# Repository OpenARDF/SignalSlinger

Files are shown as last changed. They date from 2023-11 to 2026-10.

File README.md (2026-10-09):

# SignalSlinger

SignalSlinger is an open-source 80-meter radio orienteering (ARDF) transmitter kit for the 3.5 MHz to 3.7 MHz amateur band. It supports classic, sprint, and foxoring events, with a high-accuracy real-time clock for synchronized transmissions and scheduled start and finish times.

## Product Photo

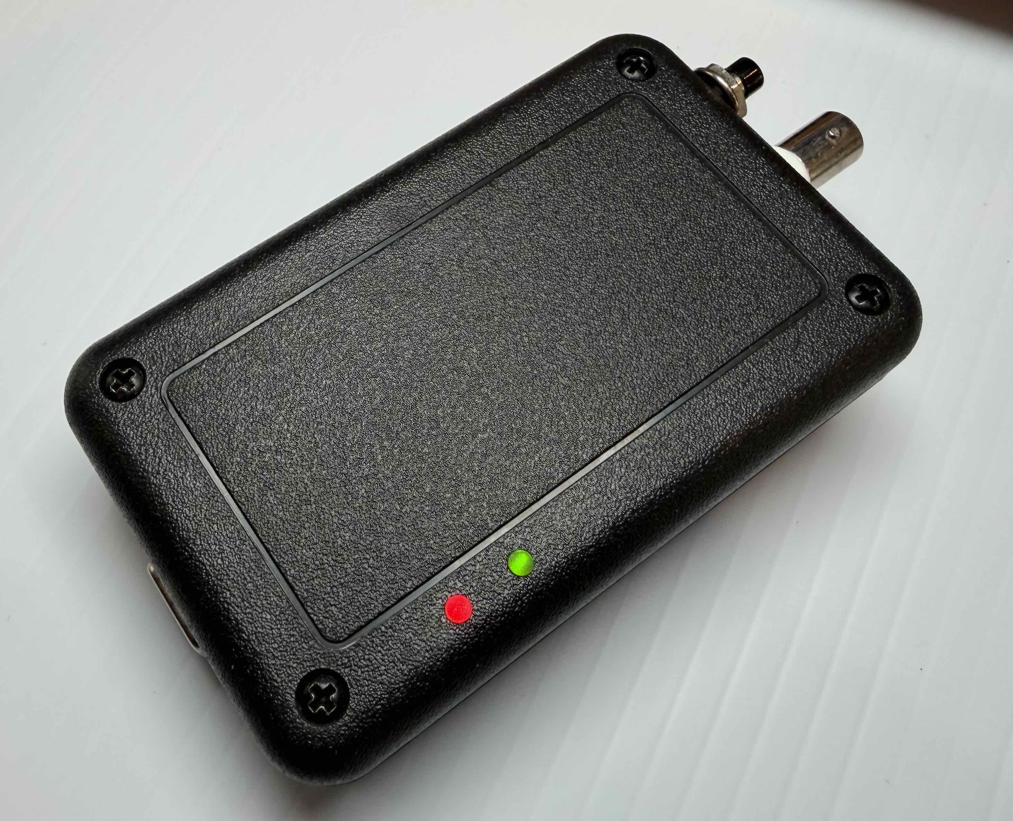
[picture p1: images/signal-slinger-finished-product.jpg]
SignalSlinger finished product


## Documentation

* [User Manual](https://docs.google.com/document/d/1eX7xH3cDyRNS-MVg13EojpP8IB8bDgrdszM48J0sn7k/edit?usp=sharing)
* [Bill of Material](https://docs.google.com/spreadsheets/d/182rCsEmR_KNoESYd0NLeVXOi867AKD0zTovbhvcYbqc/edit?usp=sharing)
* [GitHub Releases](https://github.com/OpenARDF/SignalSlinger/releases)

## Availability

SignalSlinger is available in kit form from Backwoods Orienteering Klub. [Order the SignalSlinger Transmitter Kit](https://backwoodsok.org/store/SignalSlinger-Transmitter-Kit-p799230332) or visit the product page for current pricing, availability, shipping information, and kit details.

## Updating Software

This `main` branch corresponds to the current stable firmware release. Download the update file that matches your hardware revision:

* `SignalSlinger-Update-v2.0.7-HW-3.5.hex`
* `SignalSlinger-Update-v2.0.7-HW-3.4.hex`

Use SerialSlinger for normal updates on devices that already support software updates. For first-time bootloader setup, use the matching complete release bundle and an approved programmer over the board's UPDI programming header (`P101`). Always choose the file that matches your hardware revision, and do not modify fuses or disable UPDI outside the documented setup flow.

For complete programming steps, setup-bundle usage, and hardware connection details, see the [User Manual](https://docs.google.com/document/d/1eX7xH3cDyRNS-MVg13EojpP8IB8bDgrdszM48J0sn7k/edit?usp=sharing). If you want the current development branch instead of the stable public release, switch to the `Development2` branch and use the release files referenced there.

## Firmware Development

Firmware source and build scripts live in [`Software/AVR128DA28`](Software/AVR128DA28).

For the current development workflow, start here:

* [`Software/AVR128DA28/CODEX_WORKFLOW.md`](Software/AVR128DA28/CODEX_WORKFLOW.md) for branch and patch-verification expectations
* [`Software/AVR128DA28/RELEASE_WORKFLOW.md`](Software/AVR128DA28/RELEASE_WORKFLOW.md) for release preparation and dual-target asset checks
* [`Software/AVR128DA28/build-firmware.ps1`](Software/AVR128DA28/build-firmware.ps1) for the standard local firmware build
* [`Software/AVR128DA28/verify-firmware-hashes.ps1`](Software/AVR128DA28/verify-firmware-hashes.ps1) for dual-target `.hex` build and SHA256 verification

## Related Projects

* [SignalStreamer](https://github.com/OpenARDF/SignalStreamer), a matching antenna
* [SignalSnagger](https://github.com/OpenARDF/SignalSnagger), a companion receiver project
* [SerialSlinger](https://github.com/OpenARDF/SerialSlinger), a serial terminal and logging companion for SignalSlinger configuration and monitoring

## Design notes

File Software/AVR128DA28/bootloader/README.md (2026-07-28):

# SignalSlinger Bootloader

This directory contains the first-stage SignalSlinger AVR128DA28 bootloader work.

Current scope:

- reserve an 8 KiB boot section
- keep the application start fixed at byte address `0x2000`
- use `USART1` on the existing SignalSlinger serial pins, `PC0` TX and `PC1` RX
- latch SignalSlinger power on with `POWER_ENABLE`/`PA3` before waiting for serial input
- turn both front-panel LEDs on during the bootloader startup window for immediate power-on feedback, blink them at the wake-authorization cadence when the power button is held, then pass the held-button state to the app at handoff
- stay in the bootloader when no valid app reset vector is present, when the serial updater sends `U` during the startup window, or when the front-panel switch is held during a non-power reset
- otherwise jump to the relocated application

The bootloader now accepts a deliberately small page programming protocol. It only erases or writes full, page-aligned APPCODE pages and rejects any frame whose address would touch the boot section.

The running application still accepts the `UPD` command at the normal SignalSlinger serial rate. Before issuing the software reset, the app writes a short update-request marker into `GPR1`; the bootloader consumes that marker on the next software reset and stays in update mode without relying on a narrow serial timing window. After the app resets, the bootloader runs the programming protocol at `115200` baud. On the current SignalSlinger firmware image this writes the app in about 40-45 seconds, or about a minute with default serial page-CRC verification, which is a useful improvement without pushing the serial link hard.

On SignalSlinger hardware, the front-panel switch is also the momentary power-on source. A normal cold power-on therefore starts with that switch held. The bootloader treats POR/BOR resets specially: it latches `PA3` high immediately so the board stays powered, turns both LEDs on for immediate feedback, blinks both LEDs at the wake-authorization cadence while the button remains held, ignores switch-held bootloader entry for that cold-start case, and then jumps to the app unless serial `U` arrives, the app reset vector is missing, or the app has requested update mode through `GPR1` before software reset. At app handoff, it records whether the power button is still held in `GPR0`; the app consumes that marker after its GPIO initialization so it can preserve startup LED feedback only for real held-button power-on. This lets the application take over the normal power latch/off behavior and LED policy without showing a long solid-LED hold when external power appears without a button press.

## Address Map

The AVR128DA28 has 131072 bytes of program flash and 512-byte flash pages. `BOOTSIZE` and `CODESIZE` fuses are expressed in 512-byte pages.

Initial bootloader allocation:

- `BOOTSIZE = 16` pages
- boot section: `0x00000` through `0x01FFF`
- relocated application start: `0x02000`
- `CODESIZE = 0`, leaving the remainder as application code space

## Build

From `Software/AVR128DA28` on the Windows/Microchip Studio environment:

```powershell
powershell -ExecutionPolicy Bypass -File .\build-bootloader.ps1 -Configuration Release
```

Build the matching relocated application with:

```powershell
powershell -ExecutionPolicy Bypass -File .\build-relocated-firmware.ps1 -Configuration Release
```

That helper uses a temporary makefile and injects `-Wl,--section-start=.text=0x2000`; it does not alter the normal `SignalSlinger/Release/Makefile`. It removes the previous final firmware outputs before linking and then verifies the generated map so stale non-relocated output cannot be mistaken for a bootloader-ready app image.

## Provisioning Script

Use the guarded provisioner to build, merge, program, verify, and validate a bootloader-enabled unit:

```powershell
powershell -ExecutionPolicy Bypass -File .\provision-bootloader.ps1 -Port COM6
```

Check programming PC prerequisites without touching target hardware:

```powershell
powershell -ExecutionPolicy Bypass -File .\provision-bootloader.ps1 -CheckPrereqs -SkipBuild -SkipSerialValidation
```

The script creates `tmp\SignalSlinger-bootloader-combined.hex` from the bootloader HEX and relocated app HEX, chip-erases the target, programs and verifies the combined flash image, reads fuses, verifies `CODESIZE = 0x00` and `BOOTSIZE = 0x10`, then runs the bootloader serial protocol test.

Fuse writes are deliberately opt-in:

```powershell
powershell -ExecutionPolicy Bypass -File .\provision-bootloader.ps1 -Port COM6 -ProgramFuses -ConfirmFuseWrite
```

Without those two switches, the script reads and checks fuses but does not change them.

On Windows, the provisioner uses Microchip Studio `atprogram` by default. On macOS or Windows, it can use `pymcuprog`:

```powershell
pwsh ./provision-bootloader.ps1 -Backend Pymcuprog -SkipBuild -BootloaderHexPath ./bootloader/Release/SignalSlingerBootloader.hex -ApplicationHexPath ./SignalSlinger/Release/SignalSlinger.hex
```

The PowerShell build helpers remain Windows/Microchip Studio centered. The
repository also has a pinned native macOS build path:

```sh
just avr-setup-macos
just avr-doctor
just avr-boot-chain-build
```

That build writes the bootloader and both hardware revisions of the relocated
application beneath ignored `tmp/avr-*` directories, verifies the `0x2000`
application start and 8 KiB bootloader boundary, and records hashes, sizes, and
warnings in `build-evidence.json`. See
[`BUILD_ENVIRONMENT.md`](../BUILD_ENVIRONMENT.md) for the exact compiler/device
pack and individual build recipes.

Required programming PC software:

- Windows build/provision path: PowerShell, Microchip Studio 7 with the AVR-Dx device pack and AVR GCC toolchain, Atmel-ICE drivers, and a USB serial driver for the SignalSlinger serial adapter.
- Windows or macOS provision-only path: PowerShell 7, Python, `pymcuprog`, Atmel-ICE USB access, and prebuilt bootloader/application HEX files. `pymcuprog` is installed with `python -m pip install pymcuprog`; use a Python version with available `hidapi` wheels for the host architecture.
- Bench validation path: Atmel-ICE on UPDI plus a USB serial adapter connected to SignalSlinger USART1.

## Release Package

Firmware with software-update support starts at version `2.0.0`. Firmware versions below `2.0.0` are legacy builds and should not be packaged as bootloader-capable release assets.

Build the files that should be attached to a GitHub release:

```powershell
powershell -ExecutionPolicy Bypass -File .\build-release-package.ps1
powershell -ExecutionPolicy Bypass -File .\validate-release-package.ps1
```

To build packages for both supported hardware versions:

```powershell
powershell -ExecutionPolicy Bypass -File .\build-all-release-packages.ps1
```

The packages are written under `release-packages\...` by default and use names meant to be understandable outside the firmware bench. Files that depend on the SignalSlinger hardware version include `HW-3.4` or `HW-3.5` in their name:

- `SignalSlinger-Update-...hex`: the file SerialSlinger should use for normal software updates
- `SignalSlinger-First-Install-...hex`: the file workshop setup tools should use for a new board with a programmer
- `SignalSlinger-Setup-Helper-...hex`: the helper file used by workshop setup tools
- `SignalSlinger-Release-Info-...json`: the information SerialSlinger reads automatically
- `SignalSlinger-Checksums-...txt`: optional file-integrity checks
- `README-SignalSlinger-...txt`: short plain-language notes for the release folder

The release-info JSON keeps the unavoidable details for software: board version, update speed, page size, app start address, bootloader version, protocol version, and SHA-256 hashes. Normal users should not need those details; SerialSlinger can read them and choose the right update file in the background.

Run `validate-release-package.ps1` before uploading assets. It checks that the files named by the release info are present, hashes match, the normal update starts at the app address, the first-install image includes both bootloader and app, and the bootloader helper does not overlap app space.

For GitHub releases, upload the unzipped `SignalSlinger-Update-...hex` for each supported hardware version for the common SerialSlinger update path, plus the matching versioned `SignalSlinger-...-Release-Files.zip` containing the complete set of files for that hardware version.

## Hardware Version Selection

SerialSlinger should use the firmware already running on the device as the first guide for choosing the update file. Firmware `2.0.0` and newer supports the `INF` app command at 9600 baud. It replies with compact machine-readable lines such as:

```text
* INF product=SignalSlinger update=UPD
* INF sw=2.0.0 hw=3.5 app=0x2000 baud=115200
* INF uid=314A323536384E171D00321700000000
```

The `uid` field is the AVR's factory-programmed 16-byte serial number rendered as 32 uppercase hexadecimal characters. It remains stable across firmware updates and settings changes, allowing SerialSlinger to detect when a different transmitter replaces the previously loaded unit behind the same USB serial adapter. Firmware that predates this field remains compatible and simply omits the line.

The `hw` field should match the release package `board` field and the `HW-3.4` or `HW-3.5` text in the file name before SerialSlinger enters update mode. If `INF` is not supported, SerialSlinger can fall back to parsing the older human `VER` response, for example `SW Ver: 1.2.2 HW Build: 3.5`. Firmware versions below `2.0.0` should be treated as legacy: use `RST` plus the bootloader-catch path instead of relying on `UPD`.

The `hw` field reports the hardware target used to build the currently installed application. It is the best default for normal updates, but it is not an independent hardware probe. If a board is known or suspected to have the wrong hardware build installed, SerialSlinger should offer a deliberate recovery/override path that lets the user choose the physical hardware version, then confirms the new app reports the chosen `hw` after the update.

The bootloader `?` response identifies the bootloader protocol and flash geometry, but the bootloader binary is hardware-neutral. Hardware-version selection therefore belongs to the running app response and release metadata, before the app hands control to the bootloader.

## Serial Update Frames

All multi-byte fields are little-endian. CRC is CRC-16/CCITT-FALSE initialized to `0xFFFF` and covers the command byte plus the frame body, but not the transmitted CRC bytes.

- `?`: print bootloader information
- `U`: enter or confirm bootloader update mode
- `R`: jump to the app when the app reset vector is programmed
- `E <addr:u32> <crc:u16>`: erase one 512-byte page
- `W <addr:u32> <payload:512 bytes> <crc:u16>`: write one erased 512-byte page
- `C <addr:u32> <crc:u16>`: report CRC-16/CCITT-FALSE of one 512-byte page as `OK crc 0xAAAAAAAA CCCC`

`addr` must be page-aligned and the complete page must be inside `0x02000` through `0x1FFFF`. The bootloader responds with `OK erase`, `OK write`, `OK crc ...`, or `ERR ...`. USART framing, parity, or overflow faults are reported as `ERR serial XX`.

The `?` response is intentionally machine-readable for host programmers. New fields are added append-only so host tools can keep parsing the tokens they understand:

```text
SignalSlinger BL0.13 proto=1 minproto=1 maxproto=1 app=0x2000 page=512 flash=131072 baud=115200 boot=16 write=0x2000-0x1FFFF features=appmark,pagecrc,resetlast cmds=U,R,?,E,W,C
```

The `write` field names the only flash range the bootloader will erase or program. The `features` field advertises the app reset marker (`appmark`), per-page CRC command (`pagecrc`), and reset-vector page written last for interrupted-update recovery (`resetlast`).

During a firmware update, the bootloader toggles red as erase/write flash operations are accepted and completed, and toggles green as write payload bytes are received. Rejected frames and NVM/serial errors leave red on and green off until later update activity changes the indication.

## Serial Firmware Update

Build the relocated application, then update a unit that is already running the bootloader:

```powershell
powershell -ExecutionPolicy Bypass -File .\build-relocated-firmware.ps1 -Configuration Release
powershell -ExecutionPolicy Bypass -File .\update-firmware-serial.ps1 -Port COM6 -SkipBuild -NoReset
```

For a normal field update from the running application, let the script send `UPD` to the app and catch the bootloader entry window:

```powershell
powershell -ExecutionPolicy Bypass -File .\update-firmware-serial.ps1 -Port COM6 -RequestBootloaderFromApp
```

The updater defaults to `-AppBaud 9600` for the `UPD` command and `-BootBaud 115200` for the bootloader frames. The legacy `-Baud` parameter is still accepted as an alias for `-BootBaud`.

For bench validation with Atmel-ICE attached, add `-VerifyWithUpdi` to verify the programmed app flash after the serial update:

```powershell
powershell -ExecutionPolicy Bypass -File .\update-firmware-serial.ps1 -Port COM6 -RequestBootloaderFromApp -VerifyWithUpdi
```

The updater parses the relocated Intel HEX file, rejects records outside APPCODE, erases the reset-vector page first, writes all other pages, then writes the reset-vector page last. By default it asks the bootloader for a CRC of each programmed page and compares it with the image data, giving serial-only verification without Atmel-ICE. Use `-SkipSerialVerify` only for bench timing or protocol debugging.

After sending the bootloader `R` command, the updater reopens the serial port at the app baud rate, drains startup text, sends `INF`, and confirms the updated app is running with the expected product, version, hardware version, app start address, and update baud. Use `-SkipAppConfirm` only when deliberately testing a recovery case where the app is not expected to start.

If an update is interrupted after the reset-vector page is erased, the application will not start. That is intentional: on the next reset, the missing app vector keeps the bootloader resident so the unit can be restored with:

```powershell
powershell -ExecutionPolicy Bypass -File .\update-firmware-serial.ps1 -Port COM6 -SkipBuild -NoReset -VerifyWithUpdi
```

## Bench Protocol Tests

With Atmel-ICE and the USB serial adapter attached, run the bootloader protocol hardening test from the app `UPD` path:

```powershell
powershell -ExecutionPolicy Bypass -File .\test-bootloader-serial.ps1 -Port COM6 -RequestBootloaderFromApp
```

Run the same test through UPDI reset plus serial `U` entry:

```powershell
powershell -ExecutionPolicy Bypass -File .\test-bootloader-serial.ps1 -Port COM6
```

The test uses page `0x1FE00` as scratch, validates good erase/write/CRC behavior, rejects bad CRCs, rejects unaligned, boot-section, and past-flash addresses, verifies truncated-frame timeout handling, confirms the bootloader remains responsive afterward, and erases the scratch page before returning to the app.

For repeatability testing, run multiple full updates from the app `UPD` path:

```powershell
powershell -ExecutionPolicy Bypass -File .\test-bootloader-repeatability.ps1 -Port COM6 -Count 3
```

By default each repeatability run verifies every page over serial CRC, verifies the programmed application over UPDI, and reports programming and wall-clock time. The script writes timestamped run artifacts under `tmp\bootloader-repeatability\...`: one log per update plus `summary.csv` and `summary.json` with the git commit, HEX path, HEX SHA-256, baud rates, verification settings, and per-run timings.

Use `-OutputDir <path>` to choose a durable evidence folder. Use `-SkipSerialVerify` only when measuring raw programming time; use `-NoVerify` only when Atmel-ICE is not attached.

## Provisioning Notes

Do not program bootloader fuses casually. The safe provisioning flow should remain:

1. build the bootloader
2. program the bootloader over UPDI
3. verify fuse backups exist
4. set `BOOTSIZE = 16` and `CODESIZE = 0`
5. verify `BOOTSIZE = 0x10` and `CODESIZE = 0x00`
6. build and program a relocated application
7. run `test-bootloader-serial.ps1` through both app `UPD` and UPDI reset entry
8. run one full serial update with `-VerifyWithUpdi`
9. confirm the application responds at the normal app baud

The normal production firmware makefile should remain unmodified while the relocated build path is still being proven.

## Recovery Checklist

If a unit does not start the app after an attempted update:

1. connect the USB serial adapter at `115200` baud
2. send `?` and confirm the `SignalSlinger BL...` banner
3. if there is no response, reset with UPDI while sending `U`
4. run the serial updater with `-NoReset -VerifyWithUpdi`
5. confirm the app responds at `9600` baud

If serial recovery does not respond, use UPDI to reprogram the bootloader and relocated app, then re-check `BOOTSIZE` and `CODESIZE`. Do not change fuses unless UPDI communication is known-good.

Reference validation sequence before broader use:

1. `powershell -ExecutionPolicy Bypass -File .\build-bootloader.ps1 -Configuration Release`
2. `powershell -ExecutionPolicy Bypass -File .\build-relocated-firmware.ps1 -Configuration Release`
3. `powershell -ExecutionPolicy Bypass -File .\test-bootloader-serial.ps1 -Port COM6 -RequestBootloaderFromApp`
4. `powershell -ExecutionPolicy Bypass -File .\test-bootloader-serial.ps1 -Port COM6`
5. `powershell -ExecutionPolicy Bypass -File .\test-bootloader-repeatability.ps1 -Port COM6 -Count 3`

UPDI must remain available as the recovery path throughout bootloader development.

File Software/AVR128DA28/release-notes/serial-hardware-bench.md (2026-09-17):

# Serial hardware regression bench

This bench runs production firmware on an identified attached **HW 3.5 Classic
Fox 3**, using its RTC, interrupt handlers, scheduler, serial transport, and GPIO
readback. It changes the RTC and schedule temporarily. It leaves transmissions
stopped, restores the original saved schedule and the computer's local wall clock,
and disables tracing on normal completion, assertion failure, or SIGTERM.

## Commands

Existing commands remain compatible: `UI S` reports UI/clone state, `UI P n`
queues a counted-button action directly to the foreground dispatcher, and `UI C`
clears clone UI latches. New commands extend that interface:

| Command | Function |
| --- | --- |
| `UI D` | Bench capability version, coherent state snapshot, LED/GPIO and synthesizer state, pending input, temperature freshness, runtime and last button-action/wake diagnostics. |
| `UI B 1-750` | Hold a simulated button closed for this many ordinary button-sampling periods, then release. A period is nominally 20 ms; 10 is a short press, 100 exercises hold preview, and 250 exceeds the normal long-hold threshold. |
| `UI T 1-30` | Clear and enable a 32-record RAM ring at the requested interval in RTC seconds. |
| `UI T 0` | Stop recording, preserving retained samples. |
| `UI T` | Freeze and print the ring in chronological order, ending with `UI T end`. |

`UI B` enters the normal button detector after physical debouncing. It exercises
press counting, hold preview, hold intent, long-hold thresholds, and foreground
handling. It does **not** simulate electrical bounce, the physical wake interrupt,
or hold-to-wake authorization. It refuses overlapping injection, a physically
closed button, sleeping/not-yet-authorized operation, pending sleep, master/clone
mode, and already pending button commands. It releases automatically and preserves
the pending release across standby so subsequent holds re-arm normally.

Synthetic input and timer tracing are off after reset; UART error counters start at zero. The hooks do not force transmitter
outputs, spoof temperature or RTC ticks, override thermal protection, or write
EEPROM. Normal user commands used to configure tests do write settings and session
history. Trace capture piggybacks on the existing one-second RTC interrupt, with
no serial output, ADC work, or extra scheduled wake-ups. A dump freezes recording;
it does not provide an endless live stream. At interval 10 it retains about five
minutes of samples; older samples are overwritten. Snapshots are scheduler/GPIO
observations, not calibrated RF, optical, or power measurements.

`UI D` also reports saturating UART overrun, framing, and parity error counts
since reset. Damaged lines are discarded through their terminator and produce an explicit
serial-receive error; a truncated setting must never execute. Clean lines retain
the existing parser behavior. The standard `just hardware-bench` recipe sends unpaced command bytes. The
underlying script retains its conservative 10 ms default for investigations;
`--byte-gap-ms 0` explicitly requests the unpaced regression run. Pacing was the initial diagnostic workaround for EEPROM-induced CPU stalls.
The EEPROM fix waits for readiness before reads and between multi-byte writes,
allowing already-enabled interrupts to continue. Use unpaced traffic and the
EEPROM regression gate below to verify the fix; paced success alone is insufficient. Errors are retained in evidence, never silently retried. The runner uses a kernel-exclusive serial handle on macOS
and stops on incomplete or error replies.

Snapshot/trace `at` uses device wall-clock epoch fields, **not UTC**. `onair` is the
signed slot countdown; `sleep` uses the existing runtime enum; `day` is zero-based;
`key` and `demo` are remaining 300-Hz timer ticks. `flags` is a bit mask:

| Bit value | Meaning |
| --- | --- |
| 1 | MCU is in the foreground standby loop |
| 2 | Event enabled |
| 4 | Event commenced |
| 8 | Manually launched event |
| 16 | Run until canceled |
| 32 | Last confirmed synthesizer key state |
| 64 | Synthesizer initialized |
| 128 / 256 | Red / green LED pin readback high |
| 512 | Thermal shutdown latched |
| 1024 | Current-day cancellation latched |
| 2048 | Wake authorization complete |

## Running

Use the existing serial update script after `just check` and the target firmware
build. Do not open a second serial owner. The runner checks the full requested UID,
hardware, bench capability, and Classic Fox 3 profile before changing settings.
It uses pyserial and records timestamped raw traffic plus structured case results.
Wake synchronization requires a complete INF command response; a startup banner
containing the device UID is insufficient. If startup enters sleep after the
first wake pulse, the runner sends another wake pulse before probing. Read-only
probe retries are bounded and logged; setting-changing commands are never replayed.

```
just hardware-bench /dev/cu.usbserial-DEVICE EXPECTED_FULL_UID /absolute/evidence/path
```

The recipe includes the longer quiet RTC sleep/wake and duration tests. Use the
script's `--case` option to reproduce one named scenario, or `--start-at` and
`--stop-before` to select a range. `--restore-from` accepts
a previously saved `CLK` report, useful when a firmware update reset the clock.
The original scheduled run must be stopped before dedicating a device to this
bench; this runner restores configuration and a stopped state, not prior live
execution or the prior history ring. Test timestamps use a fixed synthetic calendar
through the ordinary clock-setting protocol, while elapsed delays use real time.

On failure, read `results.json` and `serial.jsonl`; the restore result is explicit.
An abrupt host crash, power cut, or SIGKILL cannot execute software cleanup. For
fully unattended fault/soak work, add an independent hardware power/RF cutoff.
The framework does not erase history or alter calibration, callsign, frequency,
battery thresholds, thermal settings, or firmware version.

## Limits

Physical button wake and bounce, visible LED output, RF frequency/power/spectrum,
standby current, supply brownouts, and actual thermal trips require the corresponding
connected external instruments or fixture. Firmware pin/synthesizer readback is
valuable evidence but cannot establish those measurements. An unavailable instrument
is a coverage gap, never a passed test. A second device and HW 3.4 are required for
physical clone/mixed-board coverage. Both firmware targets still receive build checks.

## Optional serial latency diagnostic build

`just avr-latency-build-hw 3.5` builds a separate image in
`tmp/avr-release-relocated-hw-3-5-latency`. This enables
`SIGNALSLINGER_LATENCY_DIAGNOSTICS`; normal builds compile every timing scope out.
When first added, these hooks left the normal HW 3.5 image byte-for-byte
identical to its predecessor; subsequent functional fixes intentionally change
that image. The diagnostic image adds execution
overhead and must be identified separately in test evidence.

After installing that image with the existing serial updater:

| Command | Diagnostic behavior |
| --- | --- |
| `UI L 1` | Clear bounded timing/fault records and enable capture. |
| `UI L 0` | Disable capture, preserving records. |
| `UI L` | Freeze and report metrics plus the first 16 overflow observations. |

No timer configuration, interrupt priority, ADC, EEPROM, or scheduled wake-up is
added by the instrumentation itself. It reads the existing 32768-Hz RTC counter;
one tick is approximately 30.5 microseconds. Scope times wrap after one RTC
period (about one second), so this is a short-latency diagnostic, not a general
long-operation profiler. Captures must not span explicit clock resets. A scope's
elapsed time includes interrupts that preempt it; a long foreground operation is
not automatically evidence of interrupt starvation.

Metric IDs: 0 RTC handler, 1 TCB0 handler, 2 LED handler, 3 high-priority TCB2
handler, 4 key control, 5 I2C write, 6 I2C read, 7 EEPROM byte write, 8 EEPROM word
write, 9 EEPROM dword write, 10 EEPROM float write, 11 RX parser, 12 EEPROM read,
13 history append. `max` and `irq_max` are RTC ticks; `busy` counts entries while
EEPROM was busy; `over2ms` counts scopes lasting at least 66 ticks. TCB2's `gap`
is the longest entry-to-entry interval, normally approximately 2 ms in this build.
The scope-mask bit at position N denotes an active scope with ID N.

Fault observations require both an unread byte (`RXCIF`) and its overflow flag;
old RXDATAH error bits without RXCIF are stale, not additional overruns. Fault
records and the saturating UART error counters are observations, not a count of
individual lost bytes. `UI L 1` does not reset the UART counters.

`just serial-latency-bench PORT FULL_UID NEW_OUTPUT_DIRECTORY` runs the broader
capture sequence. The script also supports `--focus-demo --repeats 3` to repeat
the carrier-to-demo transition and capture a timed-setting write. It reuses the
hardware bench's identity checks, exclusive port, evidence log, and restoration.
The receive load consists of continuous comment text, avoiding a flood of queued
commands and replies. Selected captures prefix that text with an explicit button
or timer-setting command. A successful capture means the investigation completed;
read `latency.json` and the raw traffic to determine whether overruns occurred.
Restore the normal image and the current clock after the diagnostic session.

## EEPROM serial regression gate

`just serial-eeprom-regression PORT FULL_UID NEW_OUTPUT_DIRECTORY` repeats the
previously failing carrier-to-demo transition three times and changes a stored
finish time, under continuous 9600-baud receive traffic. It requires a diagnostic
image, zero UART overrun/framing/parity counters, no captured overflow events, and
a maximum high-priority timer service interval below 4 ms (normally about 2 ms).
It also verifies carrier/demo entry and the saved finish time, so a dropped
command cannot produce a false pass.

The underlying script accepts `--normal-image --require-clean` to exercise the
same traffic and state/error checks on ordinary firmware, omitting optional
timing commands. `--require-clean` can also be used for its broader sequence,
which covers scheduled-start and carrier-expiry transitions. Capturing evidence
without this option remains an investigation, not a zero-error regression pass.

The low-level `test-eeprom-access.py` test runs the production accessor bodies
against a busy-memory model, checking read/write readiness, ascending byte order,
floating-point bit preservation, enabled/disabled interrupt state, and partial
writes. Removing either readiness guard must fail the test. The separate journal
test covers power cuts, ring wraparound and checksum rejection; host simulation
does not substitute for physical supply-interruption testing.

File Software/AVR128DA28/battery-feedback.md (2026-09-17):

# External battery feedback

The green LED uses the most recent confirmed external-battery voltage. A healthy
battery can therefore produce steady green even while its power-control cable is
deliberately switched off. During normal status display, green blinks fast when
an internal battery is detected, its voltage is at or below the configured low
threshold (default 3.8 V), and external voltage is strictly below 6.0 V. Charging
state does not affect this indication. Other readings at or below 6.0 V produce
slow green blinking, including exactly 6.0 V; readings above 6.0 V produce steady
green. This is a voltage indication, not a capacity estimate.

Awake firmware uses the existing periodic ADC scheduler:

- A transmission or charging power-on requests a fresh external measurement after
  at least 10 ms of settling, even when the LEDs are dark.
- With visible LEDs and power already requested, external voltage is measured
  approximately once per second.
- With visible LEDs and managed external power disconnected, a temporary
  measurement client enables the battery, waits at least 10 ms, samples, and
  releases its request. This repeats approximately every ten seconds. It never
  enables the RF chain. Charging or transmission can retain power independently.
- LED timeout cancels temporary probes and disables the faster polling. Normal
  awake monitoring of an enabled supply keeps its approximately eight-second
  interval. The legacy timer constants are not changed for other services.
- With external battery control disabled, measurements never pulse the auxiliary
  output, which may be used for the HW 3.4 fan.

The periodic service completes a conversion on a subsequent 300 Hz timer tick,
so a normal probe lasts about 13 ms, with extra delay if another conversion is
in progress. A lost ADC
conversion releases the temporary request; a separate 100 ms request deadline
bounds a probe even when the ADC scheduler cannot start its conversion.

`BAT` reports the last confirmed external measurement rather than sampling the
intentionally disconnected jack. Its internal measurement and foreground
temperature reads temporarily own the ADC; any displaced periodic conversion is
retried, so results are not attributed to the wrong channel.

The ADC allows 16 ADC clocks for initialization after enabling its reference.
Temperature-channel acquisitions use 11 sample-length clocks at the 375 kHz ADC
clock (29.3 microseconds), meeting the AVR128DA sensor's 25-microsecond startup
and 28-microsecond sampling requirements. Voltage channels restore the short
sampling window. The input is selected before enabling the ADC/reference so
the initialization delay cannot retain the previous input for the first sample.
This prevents immediate `TMP` queries after ADC restart from
reporting false heat and changing the fan state. Sampling cadence and sleep
shutdown remain unchanged. `scripts/test-adc-temperature.py` exercises the
production driver across cold starts, channel switches, and shutdown.

Peripheral initialization leaves channel preparation pending. The shared channel
selector then establishes the requested input before enabling the ADC, even
when startup or standby charging code initialized it first. Blocking voltage and
temperature reads reuse one conversion helper: it aborts any displaced sample,
waits for a fresh result with a bounded counter, and disables the ADC on timeout.
Voltage failures return zero and temperature failures return an invalid value;
neither accepts the previous conversion as a successful sample. Every new
conversion clears the old result-ready flag. Callers retain their existing
interrupt guards and periodic-conversion restart notification.

The existing sleep loop, approximately 90-second sleep probe, charging decisions,
and wake schedule are unchanged. Awake probes are canceled before sleep and do
not wake the device or extend the LED timeout. No new settings are persisted.

The 10 ms settling time is an initial design allowance. Physical settling and RF
behavior on modified battery-control hardware still require bench verification.
Run `just test` for deterministic timing, arbitration, ADC recovery, and sleep
boundary checks, and `just avr-relocated-build-hw 3.4` / `3.5` for both firmware
targets.

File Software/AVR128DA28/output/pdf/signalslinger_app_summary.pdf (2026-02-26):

# SignalSlinger App Summary (Repo-based)

Evidence source: repository files only. Missing items are labeled "Not found in repo."

### What it is

SignalSlinger is AVR firmware for an AVR128DA28-based 80 m radio orienteering transmitter. The repo shows timed event transmission logic, Morse generation, RF clock/control, serial programming, and low-power operation for a field device.

### Who it’s for

Primary persona: builders/operators of an 80 m radio orienteering (ARDF/foxoring) transmitter who configure and run scheduled transmissions on dedicated hardware.

### What it does

- Schedules and runs timed transmit events with start/finish times and on-air/off-air cycles (event
state + sleep timing in main loop / RTC ISR).
- Generates Morse code patterns/IDs and supports configurable code speeds for station ID and patterns (‘morse.cpp‘, EEPROM settings).
- Controls RF transmission frequency and keying on 80 m, including Si5351-based clock generation and power gating (‘transmitter.cpp‘, ‘si5351.cpp‘).
- Stores persistent settings in MCU EEPROM, including event timing, frequencies, fox modes, power, unlock code, and calibration (‘eeprommanager.cpp/.h‘).
- Provides a serial command interface (USART0, ‘SB_BAUD‘ 9600) with command parsing/help behavior and message buffering (‘driver_isr.cpp‘, ‘serialbus.cpp‘, ‘serialbus.h‘).
- Monitors battery voltages/temperature and manages charging/load-switch behavior and thermal-related controls (‘adc.cpp‘, ‘binio.cpp‘, thresholds in ‘defs.h‘).
- Uses low-power standby/sleep with wake-up by RTC, button press, or serial port activity (‘main.cpp‘, ‘driver_init.cpp‘).

### How it works (compact architecture)

- Application orchestrator: ‘main.cpp‘ initializes drivers (‘atmel_start_init()‘), serial bus,
EEPROM-backed config, RTC calibration, and transmitter checks, then runs the foreground state machine.
- Interrupt/event layer: ‘RTC_CNT_vect‘ performs 1-second scheduling work; ‘USART0_RXC_vect‘ parses incoming serial bytes into command buffers; ‘PORTC_PORT_vect‘ can wake the unit on serial RX while sleeping.
- Device services: ‘driver_init.cpp‘ configures normal/sleep/charging hardware states; ‘rtc.cpp‘
manages internal RTC and backup clock mode; ‘ds3231.cpp‘ provides DS3231 I2C RTC support.
- RF path: foreground logic calls ‘transmitter.cpp‘, which powers RF hardware via ‘binio.cpp‘ and programs the Si5351 over ‘i2c.cpp‘/‘si5351.cpp‘; ‘morse.cpp‘ supplies keyed symbol timing/pattern encoding.
- State/persistence flow: user commands/button events update globals and EEPROM; RTC time drives event scheduling; status is reflected via LEDs and serial output. Some internals use shared global
state across ISRs/foreground.

### How to run (minimal getting started)

1. Open ‘/Users/charlesscharlau/Documents/GitHub/SignalSlinger/Software/AVR128DA28/SignalSlinger.atsln‘ in Atmel Studio 7 (solution file and ‘.cppproj‘ are present).
2. Build ‘Debug|AVR‘ or ‘Release|AVR‘ for target ‘AVR128DA28‘; generated makefiles and project settings indicate AVR GCC outputs ‘SignalSlinger.elf‘/HEX artifacts.
3. Program the target hardware via UPDI (the project config includes Atmel-ICE UPDI settings).
4. Connect to the serial interface at 9600 baud for configuration/status messages.
5. Exact board wiring, hardware bring-up, and step-by-step flashing procedure: Not found in repo.
Repo evidence used includes main.cpp, driver_init.cpp, driver_isr.cpp, defs.h, serialbus.*, transmitter.*,
rtc.cpp, ds3231.cpp, si5351.cpp, eeprommanager.*, SignalSlinger.cppproj, Release/Makefile.

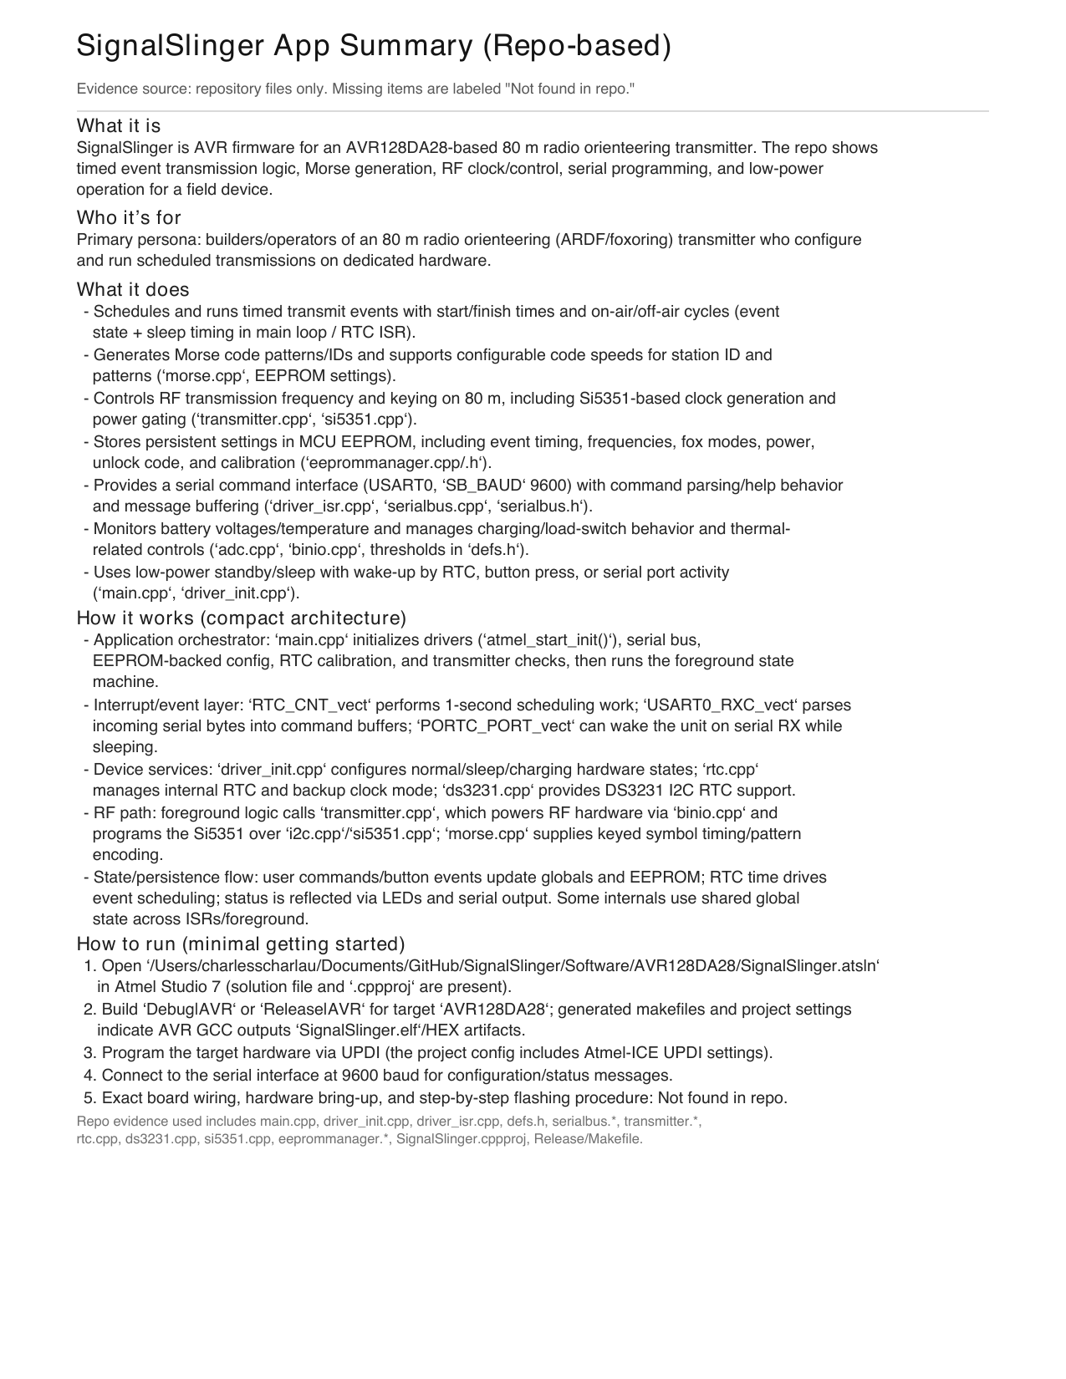
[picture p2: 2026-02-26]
Software/AVR128DA28/tmp/pdfs/signalslinger_app_summary-1.png

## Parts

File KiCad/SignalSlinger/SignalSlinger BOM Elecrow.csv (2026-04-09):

Reference | Manufacturer Part number | Qty | Original | Description | Purchase Link | Value | Datasheet | Manufacturer | Footprint | Digi-Key Part No. | LCSC Part Number
C101,C104,C105,C107,C218 | CL21B104KACNNNC | 5 | N | CAP CER 0.1UF 25V X7R 0805 | https://www.digikey.com/short/q2f22qnq | 100nF | ~ | Samsung Electro-Mechanics | Capacitor_SMD:C_0805_2012Metric | 1276-1099-1-ND | C29926
C102,C103,C106,C108,C112,C204,C217,C301 | 08051C474K4Z2A | 8 | N | CAP CER 0.47UF 100V X7R 0805 | https://www.digikey.com/products/en?keywords=478-9924-1-ND | 470nF |  | AVX Corporation | Capacitor_SMD:C_0805_2012Metric | 478-9924-1-ND | C342818
C109,C201,C203,C205,C206,C207,C208,C210,C216,C299 | C2012X5R1V106K125AC | 10 | N | CAP CER 10UF 35V X5R 0805 | https://www.digikey.com/short/p8qdn4mp | 10uF |  | TDK Corporation | Capacitor_SMD:C_0805_2012Metric | 445-14418-1-ND | C3843628
C110 | CL32A226MAJNNNE | 1 | N | CAP CER 22UF 25V X5R 1210 | https://www.digikey.com/products/en?keywords=1276-3373-1-ND | 22uF |  | Samsung Electro-Mechanics | Capacitor_SMD:C_1210_3225Metric | 1276-3373-1-ND | C337455
C111,C215 | T495X476K020ATE150 | 2 | N | CAP TANT 47UF 10% 20V 2917 | https://www.digikey.com/products/en?keywords=399-3904-1-ND | 47uF low ESR |  | KEMET | SignalSlinger_Footprints:C_2917 | 399-3904-1-ND | C122333
C202,C209 | C0805C103J5GEC7800 | 2 | N | CAP CER 0805 10NF 50V C0G 5% | https://www.digikey.com/short/qd893213 | 10nF |  | KEMET | Capacitor_SMD:C_0805_2012Metric | 399-C0805C103J5GEC7800CT-ND | C3887673
C302,C305 | GRM2195C2A112JA01D | 2 | N | 1100 pF ±5% 100V Ceramic Capacitor C0G, NP0 0805 (2012 Metric) | https://www.digikey.com/en/products/detail/murata-electronics/grm2195c2a112ja01d/8323858 | 1100pF |  | Murata Electronics | Capacitor_SMD:C_0805_2012Metric | GRM2195C2A112JA01D-ND
C303 | GCM2165C2A182GA16D | 1 | N | Multilayer Ceramic Capacitors MLCC - SMD/SMT 1800 pF 100 VDC 2% 0805 C0G (NP0) AEC-Q200 | https://www.digikey.com/en/products/detail/murata-electronics/gcm2165c2a182ga16d/17848659 | 1800pF |  | Murata Electronics | Capacitor_SMD:C_0805_2012Metric
C304 | 08051A910FAT2A | 1 | N | Multilayer Ceramic Capacitors MLCC - SMD/SMT 100V 91pF C0G 0805 1% | https://www.digikey.com/en/products/detail/kyocera-avx/08051a910fat2a/1601269 | 91pF |  | KYOCERA AVX | Capacitor_SMD:C_0805_2012Metric
D101,D102 | 1N4148WT-7 | 2 | N | DIODE GEN PURP 80V 125MA SOD523 | https://www.digikey.com/en/products/detail/diodes-incorporated/1N4148WT-7/583731 | 1N914WT |  | Diodes Incorporated | Diode_SMD:D_SOD-523 | 1N4148WTDICT-ND | C83482
D103 | LTST-C170KRKT | 1 | N | LED RED CLEAR SMD | https://www.digikey.com/en/products/detail/liteon/LTST-C170KRKT/386779 | Red LED | ~ | Lite-On Inc. | LED_SMD:LED_0805_2012Metric | 160-1415-1-ND | C94868
D104 | LTST-C170KGKT | 1 | N | LED GREEN CLEAR SMD | https://www.digikey.com/en/products/detail/liteon/LTST-C170KGKT/386777 | Green LED | ~ | Lite-On Inc. | LED_SMD:LED_0805_2012Metric | 160-1414-1-ND | C98221
D105,D106,D108,D109,D110,D111,D112 | CG0603MLC-05LE | 7 | N | VARISTOR 0603 | https://www.digikey.com/products/en?keywords=CG0603MLC-05LECT-ND | ESD9B5.0ST5G_1 |  | Bourns Inc. | Diode_SMD:D_0603_1608Metric | CG0603MLC-05LECT-ND | C316054
D107,D115,D203,D204,D206,D207 | CRS09(TE85L,Q,M) | 6 | N | DIODE SCHOTTKY 30V 1.5A SOD-123FL | https://www.digikey.com/en/products/detail/toshiba-semiconductor-and-storage/crs09-te85l-q-m/871565 | Schottky Diode |  | Toshiba Semiconductor and Storage | SignalSlinger_Footprints:D_SOD-123FL | CRS09QCT-ND
D201 | BAT54C,215 | 1 | N | DIODE ARRAY SCHOTTKY 30V SOT23 | https://www.digikey.com/en/products/detail/nexperia-usa-inc/BAT54C-215/763216 | BAT54C |  | Nexperia USA Inc. | Package_TO_SOT_SMD:SC-59 | 1727-2902-1-ND | C37704
D202 | S3AB-13-F | 1 | N | DIODE GEN PURP 50V 3A SMB | https://www.digikey.com/en/products/detail/diodes-incorporated/S3AB-13-F/814419 | B330A Schottky Diode |  | Diodes Incorporated | Diode_SMD:D_SMA | S3AB-FDICT-ND
D208,D209 | HS1AFL | 2 | N | DIODE GEN PURP 50V 1A SOD123F | https://www.digikey.com/en/products/detail/taiwan-semiconductor-corporation/HS1AFL/9602851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 | 1N4001 |  | Taiwan Semiconductor Corporation | Diode_SMD:D_SOD-123F | HS1AFLCT-ND
F201 | 0ZCG0260BF2B | 1 | N | PTC RESET FUSE 16V 2.6A 1812 | https://www.digikey.com/en/products/detail/bel-fuse-inc/0ZCG0260BF2B/4156115 | 2.6A | ~ | Bel Fuse Inc. | Fuse:Fuse_1812_4532Metric | 0ZCG0260BF2B
J201 | PJ-036AH-SMT-TR | 1 | N | CONN PWR JACK 2X5.5MM SOLDER | https://www.digikey.com/en/products/detail/cui-devices/PJ-036AH-SMT-TR/1530971 | Barrel_Jack_Switch | ~ | CUI Devices | Connector_BarrelJack:BarrelJack_CUI_PJ-036AH-SMT_Horizontal | CP-036AHPJCT-ND
L201 | WPN4020H2R2MT | 1 | N | FIXED IND 2.2UH 4.3A 48MOHM SMD | https://www.digikey.com/en/products/detail/shenzhen-sunlord-electronics-co-ltd/WPN4020H2R2MT/14119999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 | 2.2uH |  | Shenzhen Sunlord Electronics Co., Ltd. | SignalSlinger_Footprints:WPN4020H2R2MT | 3442-WPN4020H2R2MTCT-ND
P101 | 95278-101A06LF | 1 | N | CONN HEADER SMD 6POS 2.54MM | https://www.digikey.com/products/en?keywords=609-3487-1-ND | ISP/PDI |  | Amphenol ICC (FCI) | Connector_PinHeader_2.54mm:PinHeader_2x03_P2.54mm_Vertical_SMD | 609-3487-1-ND | C178294
Q101 | NTS4173PT1G | 1 | N | MOSFET P-CH 30V 1.2A SC70-3 | https://www.digikey.com/short/j97zqh7v | NTS4173PT1G |  | ONSEMI | Package_TO_SOT_SMD:SOT-323_SC-70 | NTS4173PT1GOSCT-ND
Q102 | BSS138W-7-F | 1 | N | MOSFET N-CH 50V 200MA SOT323 | https://www.digikey.com/short/m8f8nn79 | BSS138W-7-F |  | Diodes Incorporated | Package_TO_SOT_SMD:SOT-323_SC-70 | BSS138W-FDICT-ND | C24553
R101 | RC0805FR-07105KL | 1 | N | RES 105K OHM 1% 1/8W 0805 | https://www.digikey.com/en/products/detail/yageo/RC0805FR-07105KL/727548 | 105k |  | YAGEO | Resistor_SMD:R_0805_2012Metric | 311-105KCRCT-ND | C273877
R102,R110,R204 | RC0805FR-07162KL | 3 | N | RES 162K OHM 1% 1/8W 0805 | https://www.digikey.com/en/products/detail/yageo/RC0805FR-07162KL/727630 | 162k |  | YAGEO | Resistor_SMD:R_0805_2012Metric | 311-162KCRCT-ND | C273888
R103,R205 | RC0805FR-0712K4L | 2 | N | RES 12.4K OHM 1% 1/8W 0805 | https://www.digikey.com/en/products/detail/yageo/RC0805FR-0712K4L/727572 | 12.4k |  | YAGEO | Resistor_SMD:R_0805_2012Metric | 311-12.4KCRCT-ND | C137595
R104 | RMCF0805FT1K00 | 1 | N | RES 1K OHM 1% 1/8W 0805 | https://www.digikey.com/en/products/detail/stackpole-electronics-inc/RMCF0805FT1K00/1760090 | 1k |  | Stackpole Electronics Inc | Resistor_SMD:R_0805_2012Metric | RMCF0805FT1K00CT-ND | C17513
R105 | RC0805FR-10220RL | 1 | N | RES 220 OHM 1% 1/8W 0805 | https://www.digikey.com/en/products/detail/yageo/rc0805fr-10220rl/14008375 | 220 |  | Yageo | Resistor_SMD:R_0805_2012Metric | 13-RC0805FR-10220RLCT-ND
R106 | RC0805FR-0747KL | 1 | N | RES 47K OHM 1% 1/8W 0805 | https://www.digikey.com/en/products/detail/yageo/RC0805FR-0747KL/727973 | 47k |  | YAGEO | Resistor_SMD:R_0805_2012Metric | 311-47.0KCRCT-ND | C126351
R107,R108 | RNCP0805FTD10K0 | 2 | N | RES 10K OHM 1% 1/4W 0805 | https://www.digikey.com/en/products/detail/stackpole-electronics-inc/RNCP0805FTD10K0/2240262 | 10k |  | Stackpole Electronics Inc | Resistor_SMD:R_0805_2012Metric | RNCP0805FTD10K0CT-ND | C2441435
U101 | AVR128DA28T-E/SO | 1 | Y | IC MCU 8BIT 128KB FLASH 28SOIC | https://www.digikey.com/short/781hqp8f | AVR128DA28 | http://ww1.microchip.com/downloads/en/DeviceDoc/doc7707.pdf | Microchip Technology | SignalSlinger_Footprints:SOIC-28W_7.5x17.9mm_P1.27mm | 150-AVR128DA28T-E/SOCT-ND | C1870730
U102 | SI5351A-B-GT | 1 | Y | IC CLK GENERATOR 200MHZ 10MSOP | https://www.digikey.com/products/en?keywords=336-2399-5-ND | SI5351 | http://www.silabs.com/Support%20Documents/TechnicalDocs/Si5351-B.pdf | Silicon Labs | Package_SO:MSOP-10_3x3mm_P0.5mm | 336-2399-5-ND | C529366
U103,U204,U206 | TPS22810DBVT | 3 | N | Power Switch/Driver 1:1 N-Channel 2A SOT-23-6 | https://www.digikey.com/products/en?keywords=296-45304-1-ND | TPS22810DBVT | http://www.ti.com/lit/ds/symlink/tps22810.pdf | Texas Instruments | Package_TO_SOT_SMD:SOT-23-6 | 296-45304-1-ND | C2680364
U104 | LM5134BMFX/NOPB | 1 | N | IC GATE DRVR LOW-SIDE SOT23-6 | https://www.digikey.com/products/en?keywords=296-40244-1-ND | LM5134 |  | Texas Instruments | SignalSlinger_Footprints:SOT-23-6-LM5134 | 296-40244-1-ND | C2677086
U201,U202 | LP2985A-33DBVR | 2 | N | IC REG LINEAR 3.3V 150MA SOT23-5 | https://www.digikey.com/short/vr2m3rjp | LP2985-3.3 |  | Texas Instruments | Package_TO_SOT_SMD:SOT-23-5 | 296-18479-1-ND | C89826
U205 | UA78M05IDCYR | 1 | N | IC REG LINEAR 5V 500MA SOT223-4 | https://www.digikey.com/en/products/detail/texas-instruments/UA78M05IDCYR/706596 | uA7805 | http://www.ti.com/lit/ds/symlink/ua78.pdf | Texas Instruments | SignalSlinger_Footprints:SOT-223-4 | 296-17616-1-ND
X101 | ECS-327TXO-30-TR | 1 | N | OSC TCXO 32.768KHZ 3.0V SMD | https://www.digikey.com/en/products/detail/ecs-inc/ecs-327txo-30-tr/12349414 | ECS-327TXO-30-TR |  | ECS Inc. | SignalSlinger_Footprints:Oscillator_SMD_ECS_327TXO | 50-ECS-327TXO-30-CT-ND
X102 | TXETCLSANF-25.000000 | 1 | Y | XTAL OSC TCXO 25.0000MHZ SNWV | https://www.digikey.com/products/en?keywords=1664-1273-1-ND | 25 MHz |  | Taitien | SignalSlinger_Footprints:Crystal_SMD_TXETCLSANF-4Pin | 1664-1273-1-ND

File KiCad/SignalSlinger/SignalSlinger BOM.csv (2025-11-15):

Reference | Value | Datasheet | Footprint | Qty | DNP | Digi-Key Part No. | LCSC Part Number | Link | Manufacturer | Manufacturer PN | Description
BT201 | LiIon Cell | ~ | Connector_Wire:SolderWire-0.5sqmm_1x02_P4.6mm_D0.9mm_OD2.1mm | 1
BT401 | LiPo Battery |  |  | 1 |  |  |  | https://www.adafruit.com/product/1570 | Adafruit | 1570 | Lithium Ion Polymer Battery - 3.7v 100mAh
C101,C104,C105,C107,C218 | 100nF | ~ | Capacitor_SMD:C_0805_2012Metric | 5 |  | 1276-1099-1-ND | C29926 | https://www.digikey.com/short/q2f22qnq | Samsung Electro-Mechanics | CL21B104KACNNNC | CAP CER 0.1UF 25V X7R 0805
C102,C103,C106,C108,C112,C204,C217,C301 | 470nF |  | Capacitor_SMD:C_0805_2012Metric | 8 |  | 478-9924-1-ND | C342818 | https://www.digikey.com/products/en?keywords=478-9924-1-ND | AVX Corporation | 08051C474K4Z2A | CAP CER 0.47UF 100V X7R 0805
C109,C201,C203,C205,C206,C207,C208,C210,C216,C299 | 10uF |  | Capacitor_SMD:C_0805_2012Metric | 10 |  | 445-14418-1-ND | C3843628 | https://www.digikey.com/short/p8qdn4mp | TDK Corporation | C2012X5R1V106K125AC | CAP CER 10UF 35V X5R 0805
C110 | 22uF |  | Capacitor_SMD:C_1210_3225Metric | 1 |  | 1276-3373-1-ND | C337455 | https://www.digikey.com/products/en?keywords=1276-3373-1-ND | Samsung Electro-Mechanics | CL32A226MAJNNNE | CAP CER 22UF 25V X5R 1210
C111,C215 | 47uF low ESR |  | SignalSlinger_Footprints:C_2917 | 2 |  | 399-3904-1-ND | C122333 | https://www.digikey.com/products/en?keywords=399-3904-1-ND | KEMET | T495X476K020ATE150 | CAP TANT 47UF 10% 20V 2917
C202,C209 | 10nF |  | Capacitor_SMD:C_0805_2012Metric | 2 |  | 399-C0805C103J5GEC7800CT-ND | C3887673 | https://www.digikey.com/short/qd893213 | KEMET | C0805C103J5GEC7800 | CAP CER 0805 10NF 50V C0G 5%
C302,C305 | 1100pF |  | Capacitor_SMD:C_0805_2012Metric | 2 |  | GRM2195C2A112JA01D-ND |  |  | Murata Electronics | GRM2195C2A112JA01D | 1100 pF ±5% 100V Ceramic Capacitor C0G, NP0 0805 (2012 Metric)
C303 | 1800pF |  | Capacitor_SMD:C_0805_2012Metric | 1 |  |  |  |  | Murata Electronics | GCM2165C2A182GA16D | Multilayer Ceramic Capacitors MLCC - SMD/SMT 1800 pF 100 VDC 2% 0805 C0G (NP0) AEC-Q200
C304 | 91pF |  | Capacitor_SMD:C_0805_2012Metric | 1 |  |  |  |  | KYOCERA AVX | 08051A910FAT2A | Multilayer Ceramic Capacitors MLCC - SMD/SMT 100V 91pF C0G 0805 1%
D101,D102 | 1N914WT |  | Diode_SMD:D_SOD-523 | 2 |  | 1N4148WTDICT-ND | C83482 | https://www.digikey.com/en/products/detail/diodes-incorporated/1N4148WT-7/583731 | Diodes Incorporated | 1N4148WT-7 | DIODE GEN PURP 80V 125MA SOD523
D103 | Red LED | ~ | LED_SMD:LED_0805_2012Metric | 1 |  | 160-1415-1-ND | C94868 | https://www.digikey.com/en/products/detail/liteon/LTST-C170KRKT/386779 | Lite-On Inc. | LTST-C170KRKT | LED RED CLEAR SMD
D104 | Green LED | ~ | LED_SMD:LED_0805_2012Metric | 1 |  | 160-1414-1-ND | C98221 | https://www.digikey.com/en/products/detail/liteon/LTST-C170KGKT/386777 | Lite-On Inc. | LTST-C170KGKT | LED GREEN CLEAR SMD
D105,D106,D108,D109,D110,D111,D112 | ESD9B5.0ST5G_1 |  | Diode_SMD:D_0603_1608Metric | 7 |  | CG0603MLC-05LECT-ND | C316054 | https://www.digikey.com/products/en?keywords=CG0603MLC-05LECT-ND | Bourns Inc. | CG0603MLC-05LE | VARISTOR 0603
D107,D115,D203,D204,D206,D207 | Schottky Diode |  | SignalSlinger_Footprints:D_SOD-123FL | 6 |  | CRS09QCT-ND |  |  | Toshiba Semiconductor and Storage | CRS09(TE85L,Q,M) | DIODE SCHOTTKY 30V 1.5A SOD-123FL
D201 | BAT54C |  | Package_TO_SOT_SMD:SC-59 | 1 |  | 1727-2902-1-ND | C37704 | https://www.digikey.com/en/products/detail/nexperia-usa-inc/BAT54C-215/763216 | Nexperia USA Inc. | BAT54C,215 | DIODE ARRAY SCHOTTKY 30V SOT23
D202 | B330A Schottky Diode |  | Diode_SMD:D_SMA | 1 |  | S3AB-FDICT-ND |  | https://www.digikey.com/en/products/detail/diodes-incorporated/S3AB-13-F/814419 | Diodes Incorporated | S3AB-13-F | DIODE GEN PURP 50V 3A SMB
D208,D209 | 1N4001 |  | Diode_SMD:D_SOD-123F | 2 |  | HS1AFLCT-ND |  | https://www.digikey.com/en/products/detail/taiwan-semiconductor-corporation/HS1AFL/9602851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 | Taiwan Semiconductor Corporation | HS1AFL | DIODE GEN PURP 50V 1A SOD123F
F201 | 2.6A | ~ | Fuse:Fuse_1812_4532Metric | 1 |  | 0ZCG0260BF2B |  | https://www.digikey.com/en/products/detail/bel-fuse-inc/0ZCG0260BF2B/4156115 | Bel Fuse Inc. | 0ZCG0260BF2B | PTC RESET FUSE 16V 2.6A 1812
HDWR401 | Chassis Box |  |  | 1 |  |  |  | https://www.polycase.com/sl-42p?qty=1#200=99&227=163 | polycase | SL-42PMBT | 4.25 x 2.63 x 1.27 in / 107.95 x 66.80 x 32.26 mm. / 0.15 lbs
HDWR402 | LED Light Pipes |  |  | 1 |  | LFB063CTP-ND |  | https://www.digikey.com/en/products/detail/visual-communications-company-vcc/LFB063CTP/5723593 | Visual Communications Company - VCC | LFB063CTP | LIGHT PIPE ROUND 3MM
HDWR403 | PCB Screws |  |  | 1 |  |  |  | https://www.polycase.com/screws-mbr-100 | polycase | SCREWS-MBR-100 | SCREWS-MBR-100 PCB Screws
HDWR404 | Magnet Wire for RF Inductors |  |  | 1 |  |  |  |  |  |  | MAGNET WIRE
HDWR405 | FTDI Cable |  |  | 1 |  |  |  | https://www.adafruit.com/product/70 | Adafruit | 70 | FTDI Serial TTL-232 USB Cable
HDWR406 | 9POS Backshell |  |  | 1 |  | AE11006-ND |  | https://www.digikey.com/en/products/detail/assmann-wsw-components/AGP-09-IDC/1241853 | Assmann WSW Components | AGP-09/IDC | CONN BACKSHELL 9POS 180DEG GRAY
HDWR407 | LiPo Charger Module |  |  | 1 |  | 1528-1833-ND |  | https://www.digikey.com/en/products/detail/adafruit-industries-llc/1904/5054545 | Adafruit Industries LLC | 1904 | Micro-Lipo Charger for LiPo/LiIon Batt
HDWR408 | 9-Pin D Male |  |  | 1 |  | AE10972-ND |  | https://www.digikey.com/en/products/detail/assmann-wsw-components/A-DS-09-LL-Z/1241781 | Assmann WSW Components | A-DS 09 LL/Z | CONN D-SUB PLUG 9POS SLDR CUP
HDWR409 | 6-pin Angled Header |  |  | 1 |  | 929550-01-06-ND |  | https://www.digikey.com/en/products/detail/3m/929550-01-06-I/682149 | 3M | 929550-01-06-I | CONN HEADER R/A 6POS 2.54MM
HDWR410 | PCB_AND_ASSEMBLY |  |  | 1 |  |  |  |  |  |  | Printed Circuit Board(s) plus Assembly
HDWR411 | TO-220 Mounting Hardware |  |  | 1 |  | Amazon
HDWR412,HDWR414 | Shorting Jumper |  |  | 2 |  | S9345-ND |  | https://www.digikey.com/short/w0p92mhw | Sullins Connector Solutions | NPB02SVAN-RC | CONN JUMPER SHORTING 1.27MM GOLD
HDWR413 | FTDI Adapter PCB |  |  | 1 |  |  |  | https://oshpark.com/shared_projects/15SnDRmB
J101,J103,J104,J106 | Conn_01x02 | ~ | Connector_PinSocket_2.54mm:PinSocket_1x02_P2.54mm_Vertical | 4
J102 | Conn_01x03 | ~ | Connector_PinHeader_2.54mm:PinHeader_1x03_P2.54mm_Vertical | 1
J105 | Conn_01x04 | ~ | Connector_PinHeader_2.54mm:PinHeader_1x04_P2.54mm_Vertical | 1
J107 | DB9 Female |  | SignalSlinger_Footprints:DSUB-9_Female_EdgeMount_P2.77mm | 1 |  | 609-1525-ND |  | https://www.digikey.com/products/en?keywords=609-1525-ND | TH | TH
J201 | Barrel_Jack_Switch | ~ | Connector_BarrelJack:BarrelJack_CUI_PJ-036AH-SMT_Horizontal | 1 |  | CP-036AHPJCT-ND |  | https://www.digikey.com/en/products/detail/cui-devices/PJ-036AH-SMT-TR/1530971 | CUI Devices | PJ-036AH-SMT-TR | CONN PWR JACK 2X5.5MM SOLDER
J203 | External Fan Power |  | Connector_PinHeader_2.54mm:PinHeader_1x02_P2.54mm_Vertical | 1 |  | np |  | np
J204 | Controlled Fan Power |  | Connector_PinHeader_2.54mm:PinHeader_1x02_P2.54mm_Vertical | 1 |  | np |  | np
J205 | Controlled Bat Pwr | ~ | SignalSlinger_Footprints:TerminalBlock_4Ucon_1x02_P3.50mm_Horizontal | 1 |  | AdaFruit 724 |  |  | 4U Con Technology |  | TERM BLOCK HDR 4POS 3.50MM
J301 | To Antenna |  | Connector_Coaxial:BNC_Amphenol_B6252HB-NPP3G-50_Horizontal | 1 |  | ARF1065-ND |  | https://www.digikey.com/en/products/detail/amphenol-rf/31-5431/80179 | Amphenol RF | 31-5431 | CONN BNC JACK R/A 50 OHM PCB
JP101 | Jumper_3_Bridged12 | ~ | SignalSlinger_Footprints:Jumper_THT_1x03_Bridged12_P1.27mm_Vertical | 1 |  | S9014E-03-ND |  | https://www.digikey.com/short/z0ntzpw3 | Sullins Connector Solutions | GRPB031VWVN-RC | CONN HEADER VERT 3POS 1.27MM
JP102 | Jumper_2_Bridged | ~ | SignalSlinger_Footprints:Jumper_THT_1x02_P1.27mm_Vertical | 1 |  | S9014E-02-ND |  | https://www.digikey.com/short/4w5ttcv3 | Sullins Connector Solutions | GRPB021VWVN-RC | CONN HEADER VERT 2POS 1.27MM
JP201 | V-ext disable | ~ | Jumper:SolderJumper-2_P1.3mm_Bridged_RoundedPad1.0x1.5mm | 1
JP202 | Ext-to-Linear | ~ | Jumper:SolderJumper-2_P1.3mm_Open_RoundedPad1.0x1.5mm | 1 |  | np |  | np | np
JP203 | Ext-to-Boost | ~ | Jumper:SolderJumper-2_P1.3mm_Bridged_RoundedPad1.0x1.5mm | 1
JP204 | Internal_V_Enable | ~ | Jumper:SolderJumper-2_P1.3mm_Open_RoundedPad1.0x1.5mm | 1 |  | np |  | np | np
L101 | 9T #24 Bifilar T50-43 |  | SignalSlinger_Footprints:Toroid_T-50A_TH_BF_CT_Vertical | 1 |  | FT50A-43 (Amidon) |  | http://www.amidoncorp.com/ft-50A-43/ | TH | TH | TH
L201 | 2.2uH |  | SignalSlinger_Footprints:WPN4020H2R2MT | 1 |  | 3442-WPN4020H2R2MTCT-ND |  | https://www.digikey.com/en/products/detail/shenzhen-sunlord-electronics-co-ltd/WPN4020H2R2MT/14119999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 | Shenzhen Sunlord Electronics Co., Ltd. | WPN4020H2R2MT | FIXED IND 2.2UH 4.3A 48MOHM SMD
L301,L302 | 2.7uH |  | SignalSlinger_Footprints:Toroid_T-60_2TH_Vertical | 2 |  | T60-2 (Amidon) |  | http://www.amidoncorp.com/t60-2/ | TH | TH | TH
MOD201 | AdaFruit Charger | ~ | Connector_PinHeader_2.54mm:PinHeader_1x04_P2.54mm_Vertical | 1 |  | 1528-1833-ND |  | https://www.digikey.com/en/products/detail/adafruit-industries-llc/1904/5054545 | AdaFruit | Product ID: 1904 | LI-ION LI-POLYMER CHARGER BOARD
P101 | ISP/PDI |  | Connector_PinHeader_2.54mm:PinHeader_2x03_P2.54mm_Vertical_SMD | 1 |  | 609-3487-1-ND | C178294 | https://www.digikey.com/products/en?keywords=609-3487-1-ND | Amphenol ICC (FCI) | 95278-101A06LF | CONN HEADER SMD 6POS 2.54MM
Q101 | NTS4173PT1G |  | Package_TO_SOT_SMD:SOT-323_SC-70 | 1 |  | NTS4173PT1GOSCT-ND |  | https://www.digikey.com/short/j97zqh7v | ONSEMI | NTS4173PT1G | MOSFET P-CH 30V 1.2A SC70-3
Q102 | BSS138W-7-F |  | Package_TO_SOT_SMD:SOT-323_SC-70 | 1 |  | BSS138W-FDICT-ND | C24553 | https://www.digikey.com/short/m8f8nn79 | Diodes Incorporated | BSS138W-7-F | MOSFET N-CH 50V 200MA SOT323
Q103 | IRF610 |  | SignalSlinger_Footprints:TO-220_Neutral123_Vertical_LargePads | 1 |  | IRF610PBF-ND |  | https://www.digikey.com/products/en?keywords=IRF610PBF-ND | TH | TH | TH
R1,R2 | TBD |  | Resistor_THT:R_Axial_DIN0204_L3.6mm_D1.6mm_P2.54mm_Vertical | 2 |  | TBD
R101 | 105k |  | Resistor_SMD:R_0805_2012Metric | 1 |  | 311-105KCRCT-ND | C273877 | https://www.digikey.com/en/products/detail/yageo/RC0805FR-07105KL/727548 | YAGEO | RC0805FR-07105KL | RES 105K OHM 1% 1/8W 0805
R102,R110,R204 | 162k |  | Resistor_SMD:R_0805_2012Metric | 3 |  | 311-162KCRCT-ND | C273888 | https://www.digikey.com/en/products/detail/yageo/RC0805FR-07162KL/727630 | YAGEO | RC0805FR-07162KL | RES 162K OHM 1% 1/8W 0805
R103,R205 | 12.4k |  | Resistor_SMD:R_0805_2012Metric | 2 |  | 311-12.4KCRCT-ND | C137595 | https://www.digikey.com/en/products/detail/yageo/RC0805FR-0712K4L/727572 | YAGEO | RC0805FR-0712K4L | RES 12.4K OHM 1% 1/8W 0805
R104 | 1k |  | Resistor_SMD:R_0805_2012Metric | 1 |  | RMCF0805FT1K00CT-ND | C17513 | https://www.digikey.com/en/products/detail/stackpole-electronics-inc/RMCF0805FT1K00/1760090 | Stackpole Electronics Inc | RMCF0805FT1K00 | RES 1K OHM 1% 1/8W 0805
R105 | 220 |  | Resistor_SMD:R_0805_2012Metric | 1 |  | 13-RC0805FR-10220RLCT-ND |  | https://www.digikey.com/en/products/detail/yageo/rc0805fr-10220rl/14008375 | Yageo | RC0805FR-10220RL | RES 220 OHM 1% 1/8W 0805
R106 | 47k |  | Resistor_SMD:R_0805_2012Metric | 1 |  | 311-47.0KCRCT-ND | C126351 | https://www.digikey.com/en/products/detail/yageo/RC0805FR-0747KL/727973 | YAGEO | RC0805FR-0747KL | RES 47K OHM 1% 1/8W 0805
R107,R108 | 10k |  | Resistor_SMD:R_0805_2012Metric | 2 |  | RNCP0805FTD10K0CT-ND | C2441435 | https://www.digikey.com/en/products/detail/stackpole-electronics-inc/RNCP0805FTD10K0/2240262 | Stackpole Electronics Inc | RNCP0805FTD10K0 | RES 10K OHM 1% 1/4W 0805
R109 | 47 0.5W | ~ | Resistor_THT:R_Axial_DIN0204_L3.6mm_D1.6mm_P2.54mm_Vertical | 1
SW101 | SW_SPST | ~ | SignalSlinger_Footprints:SW_SPST_TL1014BF160QG | 1 |  | EG5042CT-ND |  | https://www.digikey.com/en/products/detail/e-switch/TL1014BF160QG/3910805 | E-Switch | TL1014BF160QG | SWITCH TACTILE SPST-NO 0.05A 12V
TP101 | I2C1 |  | Connector_PinHeader_2.54mm:PinHeader_1x04_P2.54mm_Vertical | 1 |  | np |  | np | np
U101 | AVR128DA28 | http://ww1.microchip.com/downloads/en/DeviceDoc/doc7707.pdf | SignalSlinger_Footprints:SOIC-28W_7.5x17.9mm_P1.27mm | 1 |  | 150-AVR128DA28T-E/SOCT-ND | C1870730 | https://www.digikey.com/short/781hqp8f | Microchip Technology | AVR128DA28T-E/SO | IC MCU 8BIT 128KB FLASH 28SOIC
U102 | SI5351 | http://www.silabs.com/Support%20Documents/TechnicalDocs/Si5351-B.pdf | Package_SO:MSOP-10_3x3mm_P0.5mm | 1 |  | 336-2399-5-ND | C529366 | https://www.digikey.com/products/en?keywords=336-2399-5-ND | Silicon Labs | SI5351A-B-GT | IC CLK GENERATOR 200MHZ 10MSOP
U103,U204,U206 | TPS22810DBVT | http://www.ti.com/lit/ds/symlink/tps22810.pdf | Package_TO_SOT_SMD:SOT-23-6 | 3 |  | 296-45304-1-ND | C2680364 | https://www.digikey.com/products/en?keywords=296-45304-1-ND | Texas Instruments | TPS22810DBVT | Power Switch/Driver 1:1 N-Channel 2A SOT-23-6
U104 | LM5134 |  | SignalSlinger_Footprints:SOT-23-6-LM5134 | 1 |  | 296-40244-1-ND | C2677086 | https://www.digikey.com/products/en?keywords=296-40244-1-ND | Texas Instruments | LM5134BMFX/NOPB | IC GATE DRVR LOW-SIDE SOT23-6
U201,U202 | LP2985-3.3 |  | Package_TO_SOT_SMD:SOT-23-5 | 2 |  | 296-18479-1-ND | C89826 | https://www.digikey.com/short/vr2m3rjp | Texas Instruments | LP2985A-33DBVR | IC REG LINEAR 3.3V 150MA SOT23-5
U203 | TO-220 ADJ Reg. | https://www.analog.com/media/en/technical-documentation/data-sheets/1086ffs.pdf | Package_TO_SOT_THT:TO-220-3_Horizontal_TabDown | 1 |  | 505-LT1086CT#PBF-ND |  | https://www.digikey.com/en/products/detail/analog-devices-inc/LT1086CT-PBF/891238 | Analog Devices Inc. | LT1086CT#PBF | IC REG LIN POS ADJ 1.5A TO220-3
U205 | uA7805 | http://www.ti.com/lit/ds/symlink/ua78.pdf | SignalSlinger_Footprints:SOT-223-4 | 1 |  | 296-17616-1-ND |  | https://www.digikey.com/en/products/detail/texas-instruments/UA78M05IDCYR/706596 | Texas Instruments | UA78M05IDCYR | IC REG LINEAR 5V 500MA SOT223-4
W101 | T2 |  | SignalSlinger_Footprints:Measurement_Point_ScopeProbe_Round-SMD-2sides-Pad_Small | 1 |  | np |  | np
W102 | T3 |  | SignalSlinger_Footprints:Measurement_Point_ScopeProbe_Round-SMD-2sides-Pad_Small | 1 |  | np |  | np
W103 | T4 |  | SignalSlinger_Footprints:Measurement_Point_ScopeProbe_Round-SMD-2sides-Pad_Small | 1 |  | np |  | np
W301 | T5 |  | SignalSlinger_Footprints:Measurement_Point_ScopeProbe_Round-SMD-2sides-Pad_Small | 1 |  | np |  | np
W302 | T6 |  | SignalSlinger_Footprints:Measurement_Point_ScopeProbe_Round-SMD-2sides-Pad_Small | 1 |  | np |  | np
W303 | T7 |  | SignalSlinger_Footprints:Measurement_Point_ScopeProbe_Round-SMD-2sides-Pad_Small | 1 |  | np |  | np
X101 | ECS-327TXO-30-TR |  | SignalSlinger_Footprints:Oscillator_SMD_ECS_327TXO | 1 |  | 50-ECS-327TXO-30-CT-ND |  |  | ECS Inc. | ECS-327TXO-30-TR | OSC TCXO 32.768KHZ 3.0V SMD
X102 | 25 MHz |  | SignalSlinger_Footprints:Crystal_SMD_TXETCLSANF-4Pin | 1 |  | 1664-1273-1-ND |  | https://www.digikey.com/products/en?keywords=1664-1273-1-ND | Taitien | TXETCLSANF-25.000000 | XTAL OSC TCXO 25.0000MHZ SNWV

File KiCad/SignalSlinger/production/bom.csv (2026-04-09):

Designator | Footprint | Quantity | Value | LCSC Part #
C101, C104, C105, C107, C218 | 0805 | 5 | 100nF
C102, C103, C106, C108, C112, C204, C217, C301 | 0805 | 8 | 470nF
C109, C201, C203, C205, C206, C207, C208, C210, C216, C299 | 0805 | 10 | 10uF
C110 | 1210 | 1 | 22uF
C111, C215 | C_2917 | 2 | 47uF low ESR
C202, C209 | 0805 | 2 | 10nF
C302, C305 | 0805 | 2 | 1100pF
C303 | 0805 | 1 | 1800pF
C304 | 0805 | 1 | 91pF
D101, D102 | D_SOD-523 | 2 | 1N914WT
D103 | 0805 | 1 | Red LED
D104 | 0805 | 1 | Green LED
D105, D106, D108, D109, D110, D111, D112 | 0603 | 7 | ESD9B5.0ST5G_1
D107, D115, D203, D204, D206, D207 | D_SOD-123FL | 6 | Schottky Diode
D201 | SC-59 | 1 | BAT54C
D202 | D_SMB | 1 | B330A Schottky Diode
D208, D209 | D_SOD-123F | 2 | 1N4001
F201 | 1812 | 1 | 2.6A
J101, J103, J104, J106 | PinSocket_1x02_P2.54mm_Vertical | 4 | Conn_01x02
J102 | PinHeader_1x03_P2.54mm_Vertical | 1 | Conn_01x03
J105 | PinHeader_1x04_P2.54mm_Vertical | 1 | Conn_01x04
J107 | DSUB-9_Female_EdgeMount_P2.77mm | 1 | DB9 Female
J201 | BarrelJack_CUI_PJ-036AH-SMT_Horizontal | 1 | Barrel_Jack_Switch
J203 | PinHeader_1x02_P2.54mm_Vertical | 1 | External Fan Power
J204 | PinHeader_1x02_P2.54mm_Vertical | 1 | Controlled Fan Power
J205 | TerminalBlock_4Ucon_1x02_P3.50mm_Horizontal | 1 | Controlled Bat Pwr
J301 | BNC_Amphenol_B6252HB-NPP3G-50_Horizontal | 1 | To Antenna
JP101 | Jumper_THT_1x03_Bridged12_P1.27mm_Vertical | 1 | Jumper_3_Bridged12
JP102 | Jumper_THT_1x02_P1.27mm_Vertical | 1 | Jumper_2_Bridged
JP201 | SolderJumper-2_P1.3mm_Bridged_RoundedPad1.0x1.5mm | 1 | V-ext disable
JP202 | SolderJumper-2_P1.3mm_Open_RoundedPad1.0x1.5mm | 1 | Ext-to-Linear
JP203 | SolderJumper-2_P1.3mm_Bridged_RoundedPad1.0x1.5mm | 1 | Ext-to-Boost
JP204 | SolderJumper-2_P1.3mm_Open_RoundedPad1.0x1.5mm | 1 | Internal_V_Enable
L101 | Toroid_T-50A_TH_BF_CT_Vertical | 1 | 9T #24 Bifilar T50-43
L201 | WPN4020H2R2MT | 1 | 2.2uH
L301 | Toroid_T-60_2TH_Vertical | 1 | 2.7uH
L302 | Toroid_T-60_2TH_Vertical2 | 1 | 2.7uH
MOD201 | PinHeader_1x04_P2.54mm_Vertical | 1 | AdaFruit Charger
P101 | PinHeader_2x03_P2.54mm_Vertical_SMD | 1 | ISP/PDI
Q101 | SOT-323_SC-70 | 1 | NTS4173PT1G
Q102 | SOT-323_SC-70 | 1 | BSS138W-7-F
Q103 | TO-220_Neutral123_Vertical_LargePads | 1 | IRF610
R1, R2 | R_Axial_DIN0204_L3.6mm_D1.6mm_P2.54mm_Vertical | 2 | TBD
R101 | 0805 | 1 | 105k
R102, R110, R204 | 0805 | 3 | 162k
R103, R205 | 0805 | 2 | 12.4k
R104 | 0805 | 1 | 1k
R105 | 0805 | 1 | 220
R106 | 0805 | 1 | 47k
R107, R108 | 0805 | 2 | 10k
R109 | R_Axial_DIN0204_L3.6mm_D1.6mm_P2.54mm_Vertical | 1 | 47 0.5W
SW101 | SW_SPST_TL1014BF160QG | 1 | SW_SPST
TP101 | PinHeader_1x04_P2.54mm_Vertical | 1 | I2C1
U101 | SOIC-28W_7.5x17.9mm_P1.27mm | 1 | AVR128DA28
U102 | MSOP-10_3x3mm_P0.5mm | 1 | SI5351
U103, U204, U206 | SOT-23-6 | 3 | TPS22810DBVT
U104 | SOT-23-6-LM5134 | 1 | LM5134
U201, U202 | SOT-23-5 | 2 | LP2985-3.3
U203 | TO-220-3_Horizontal_TabDown | 1 | TO-220 ADJ Reg.
U205 | SOT-223-4 | 1 | uA7805
W101 | Measurement_Point_ScopeProbe_Round-SMD-2sides-Pad_Small | 1 | T2
X101 | Oscillator_SMD_ECS_327TXO | 1 | ECS-327TXO-30-TR
X102 | Crystal_SMD_TXETCLSANF-4Pin | 1 | 25 MHz

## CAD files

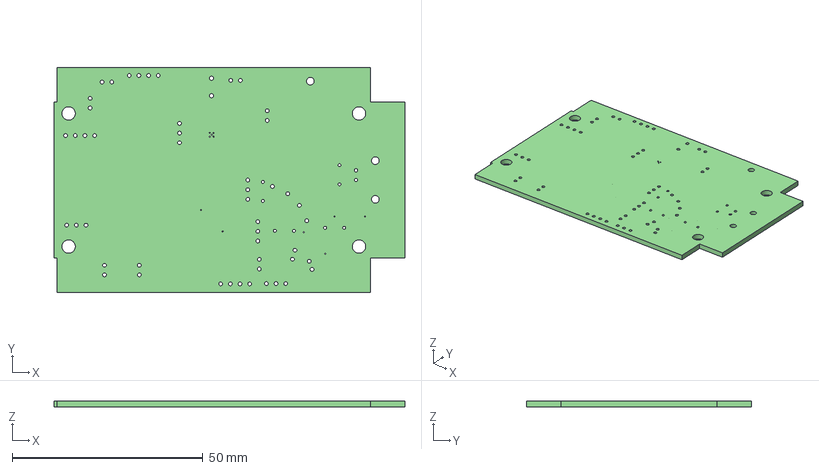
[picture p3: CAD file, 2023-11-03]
KiCad/SignalSlinger/SignalSlinger.step
92.1 x 59.1 x 1.60 mm

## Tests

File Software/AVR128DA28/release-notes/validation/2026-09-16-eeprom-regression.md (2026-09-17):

# EEPROM readiness fix: implementation and attached-device verification

Local firmware 2.0.5; HW 3.5, UID 42348279800036200109013300000000, bootloader BL0.13.
The final regression gates passed. The initial runner failure and its correction
are documented below. The attached unit retains the normal fixed firmware.
Original saved schedule and current host-local clock were restored, transmissions
were stopped, and optional tracing was disabled. Bench events remain in the bounded
session history; the original history is preserved in the pre-test snapshot.
At the time of this test run, no commit, push, tag or publication had occurred.

## Narrow production change

`SignalSlinger/src/eeprommanager.cpp` now polls EEPROM readiness before each read
and writes words, double words and floats through the existing byte writer,
waiting between bytes. Polling preserves the caller's interrupt state; already
enabled interrupts continue during the wait. EEPROM persistence remains startup
or foreground work; interrupt handlers queue session persistence for foreground
processing. No interrupts are forcibly enabled. The final byte remains asynchronous.

The EEPROM image/layout, stored representations, ascending byte order, journal
checksum and final magic-byte commit ordering are unchanged. The generated
EEPROM image is byte-identical to the pre-fix image (SHA-256
`1450f5c43bf9e37f9c245b3297d38763f710397a2f5938bdd75fe393479ba22f`).
No event scheduling, button policy, timer configuration, interrupt priorities, or thermal logic changed
in this fix. The scoped difference is retained in `eeprom-fix-only.patch`.

## Before and after on the same device

| Reproduction under continuous 9600-baud receive traffic | Before | Fixed diagnostic build |
| --- | --- | --- |
| Carrier to demo, three independent trials | One overrun per trial; timer gaps 10.83–11.51 ms | No overruns; maximum gap 2.014 ms |
| Stored finish-time write | One overrun; timer gap 10.254 ms | No overruns; maximum gap 2.014 ms |

EEPROM programming still takes approximately 10 ms per byte operation.
The fix prevents that wait from halting interrupt service. For example, the fixed
finish-time write still takes approximately 30 ms overall while the high-priority
timer continues at its ordinary approximately 2 ms interval. These are MCU timing
observations, not external waveform measurements.

Fourteen diagnostic captures passed: three carrier entries, three demo entries,
a finish-time write, idle operation, future carrier/demo entries, running demo
and scheduled Morse, scheduled start, and carrier entry/expiry. Maximum timer gap
across all captures: 2.014 ms. No overflow observations or UART overrun,
framing or parity errors were recorded.

The normal build separately passed seven continuous-traffic reproductions, and
all 24 hardware behavior cases using unpaced command bytes. Every recorded UART
snapshot in all four runs reported zero errors, including setup and restoration
snapshots. The runner verifies applied carrier/demo commands and finish-time
readback, so dropped test commands cannot masquerade as success.

## Automated validation

- `just check`: passed, including storage power-cut/CRC/ring recovery, scheduling,
  button policy/input, UART damaged-line rejection, thermal, battery, ADC and
  latency accounting checks.
- New actual-accessor busy-memory tests: read/write readiness, byte order,
  floating-point representations, enabled/disabled interrupt-state preservation,
  partial writes, and two deliberately broken readiness variants rejected.
- Normal HW 3.4 and HW 3.5 builds, plus diagnostic HW 3.5: zero compiler warnings.
- Generated AVR code reviewed: readiness polling precedes access, and multi-byte
  writers invoke the byte writer for each byte.
- Serial updater verified all 211 diagnostic-image pages and all 205 normal-image
  pages, then confirmed application 2.0.5/HW 3.5 after each flash.

## Normal-firmware behavior cases

1. PASS — hook limits and idle readback
2. PASS — timed short press and carrier cancellation
3. PASS — future carrier-demo-schedule sequence
4. PASS — future triple press clears temporary tests
5. PASS — active triple press advances one day
6. PASS — active off-air long hold cancels today
7. PASS — active on-air long hold cancels today
8. PASS — last-day hold stays canceled after serial wake
9. PASS — future long hold preserves schedule
10. PASS — preview hold release is ignored
11. PASS — timed triple press advances today
12. PASS — scheduled start during hold preserves today
13. PASS — active carrier long hold preserves phase
14. PASS — future demo long hold preserves schedule
15. PASS — 30-second carrier expiry restores phase
16. PASS — demo expiry restores future schedule
17. PASS — carrier expires while held without canceling today
18. PASS — expired schedule manual run is indefinite
19. PASS — clockless manual run and cancellation
20. PASS — natural off-air sleep and RTC wake
21. PASS — timed finish advances normally
22. PASS — manual run outlives expired duration
23. PASS — disabled equal-time schedule manual run
24. PASS — serial replies during an active event

## Retained initial failure and runner correction

The first normal-firmware run passed 18 cases, then the clockless-reset case
failed with a framing error and zero overruns. The startup banner contained the
expected UID, and the old runner incorrectly accepted that as an INF command
response while the device was waking. The runner now detects startup entering
sleep after its first wake pulse and requires a complete INF response (product,
software, bootloader and UID) before proceeding. No firmware change was needed.
The original failed run is retained in `ss-eeprom-normal-full/`.

The isolated retry passed with zero UART errors after reset (its initial snapshot
still contained the previous failed run's one framing error). A new host regression
test rejects banner-only replies, handles startup power-off, and bounds read-only
probe retries. The final full 24-case run was repeated from the beginning and is
retained in `ss-eeprom-normal-full-verified/`; all its UART snapshots were clean.

## Scope limits

The bench observes MCU state, GPIO/synthesizer readback and timing counters.
Physical button wake and contact bounce, RF frequency/power/waveform, visible LEDs,
standby current, real supply interruption and actual thermal trips were not measured.
Power-cut recovery tests are host simulations. HW 3.4 was built but not flashed or
physically tested. These limits remain explicit; they are not passed checks.

## Reproduction and evidence

The runner snapshots, raw timestamped serial logs, JSON results, build evidence,
firmware images, source snapshots and SHA-256 digests are retained beside this
report. The previous failing captures remain in `../serial-latency/`.

Use `just serial-eeprom-regression PORT UID NEW_OUTPUT_DIRECTORY` with the diagnostic
image. For normal firmware use `scripts/run-serial-latency.py` with
`--focus-demo --repeats 3 --require-clean --normal-image`; use `--restore-from`
with a saved pre-flash clock report. The full hardware suite uses
`--extended --byte-gap-ms 0`. No two processes may own the port concurrently.

### Firmware HEX SHA-256

- hw-3-5-latency: `a9afd57e387099bce66c4f61cd5b60a49fd8294f2b917c45eec569aa883c4b75`
- hw-3-5: `60b4f83232955c0bdf81e00f6db7b178823011b6cdc413664d12c06e487b2be2`
- hw-3-4: `5cc66886cc927ffcfd9e5cef765c4aeea48b133d77c06450f8f4163b9966027c`

Raw captures and source snapshots are retained locally under `Software/AVR128DA28/tmp/hardware-bench/2026-09-16/eeprom-fix/`. Generated binaries are not tracked source.

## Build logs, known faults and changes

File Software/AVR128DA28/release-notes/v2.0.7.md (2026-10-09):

# SignalSlinger 2.0.7

SignalSlinger 2.0.7 adds persistent RF frequency calibration and a dedicated
calibration carrier for accurate alignment of individual transmitters.

## User-visible changes

- `FRE CF frequency` selects and immediately keys a temporary calibration
  carrier. Whole-number frequencies use kHz and decimal frequencies use MHz;
  the supported range is 8 kHz through 160 MHz. This carrier frequency is
  volatile and returns to the 3.600 MHz default after restart.
- `FRE C offset` applies an offset in Hz, immediately retunes the active
  carrier, and saves the corresponding oscillator correction in EEPROM. The
  correction is restored automatically after every restart.
- `FRE C` reports the applied offset and the stored parts-per-billion
  correction. `FRE C X`, or any physical button press, exits calibration mode
  without changing the last saved correction.

## Stability and reliability

- Calibration changes are transactional: RF is powered and retuned before a
  correction is saved, and failed frequency or keying operations restore the
  preceding correction, frequency, power, and key state.
- Changing the Si5351 reference correction invalidates its cached PLL plan so
  the next frequency update always programs parameters calculated from the new
  correction.
- The EEPROM layout migrates the former reserved calibration slot without
  moving existing settings or the session-history journal. New host tests cover
  parsing, correction arithmetic, persistence ordering, rollback, carrier
  entry/exit, and button-exit behavior.

## Release files

- `SignalSlinger-Update-v2.0.7-HW-3.4.hex`
- `SignalSlinger-v2.0.7-HW-3.4-Release-Files.zip`
- `SignalSlinger-Update-v2.0.7-HW-3.5.hex`
- `SignalSlinger-v2.0.7-HW-3.5-Release-Files.zip`

## Full changelog

[Compare v2.0.6...v2.0.7](https://github.com/OpenARDF/SignalSlinger/compare/v2.0.6...v2.0.7)

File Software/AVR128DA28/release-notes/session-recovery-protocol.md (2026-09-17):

# Session recovery and history (EVT version 1)

SignalSlinger firmware 2.0.4 defaults thermal protection to enabled at 65 C. Legacy, erased and unknown EEPROM choice bytes migrate to that default. Explicit enabled (0xA5) and disabled (0x5A) choices saved by this firmware are preserved. Existing configuration offsets remain unchanged.

Scheduled sessions pause with RF off on overheating or loss of a fresh temperature reading. After overheating, they resume in the same window when both the latest and filtered temperatures are at or below threshold minus 5 C. Recovery also requires a fresh reading and normal schedule and user authorization. The original finish time and later days remain unchanged. Manual test sessions stop and require another user command. Normal Morse key-up and off-air slots are not session interruptions.

Calendar progress is separate from successful execution: passing a finish time reduces remaining windows but does not prove completion. A session that resumed after a pause finishes with interruptions. A session still paused at its finish is interrupted. A past window without an observed finish is expired, with completion unconfirmed.

`EVT` retains its older human-readable replies and adds:

```text
* Session state: v=1 action=2 reason=2 remaining=3 blocked=1
* Session history: v=1 count=1 capacity=7
* Session record: v=1 seq=42 base=1788526800 start=1788526800 finish=1788559200 at=1788527000 action=2 reason=2 flags=7 temp=651 limit=65
```

- Actions: 0 waiting/idle; 1 started; 2 paused; 3 resumed; 4 completed; 5 finished with interruptions; 6 interrupted; 7 expired.
- Reasons: 0 unavailable; 1 scheduled finish; 2 overheating; 3 user stop; 4 settings changed; 5 power loss/reset; 6 clock changed; 7 temperature unavailable; 8 transmissions disabled; 9 test timer finished.
- `remaining` counts current/future calendar windows, including a paused current window. It never counts successful days.
- `base`, `start`, `finish`, `at` encode the device wall-clock fields as epoch seconds. They are not UTC instants: decode their calendar fields without applying the phone or desktop timezone offset. `base` identifies the saved schedule; `start`/`finish` identify one daily window. Manual key tests use base zero. `at=0` with the valid-time flag clear means unknown time, especially for an unexpected power loss/reset. A reset can establish interruption but cannot establish the physical power-loss time.
- `temp` is the safety temperature in tenths of C (the higher of the fresh raw and filtered reading), or -32768 when unavailable; `limit` is C.
- Flag bits: 1 valid device time; 2 this window has an interruption; 4 scheduled session; 128 earlier history unavailable.
- The unused EEPROM tail holds seven recent 30-byte records on AVR128DA28. Sequence numbers wrap at 32 bits; chronological comparison uses signed differences. Each record has version and CRC checks, with its valid marker committed last. Rotation and RAM queue overflow mark history as incomplete. This is a recent history, not a permanent event archive.
- A boot following an active persisted record adds an interrupted/reset record with unknown time. No record claims continuous RF output: these are scheduler lifecycle observations, not an RF power measurement.

SerialSlinger accepts only version 1 records, deduplicates sequences within the connected device, clears history on identity changes and shows reasons and device times on Android and desktop. Older firmware continues to work; calendar-only results say expired with completion unconfirmed. Completion applies to the last recorded session, not all configured days. Full received records also remain in normal app logs.

Validation: `just test` covers thermal policy, legacy migration, the actual EEPROM journal with simulated power cuts, and production runtime/scheduler helpers under a deterministic clock. Hardware temperature/fan response and actual RF output still require device testing.

## Manual runs and button-wake diagnostics

An authorized button wake preserves an existing manual run's loaded window and
cycle countdown, independently of whether the saved calendar schedule has expired.
Indefinite runs also survive when Start equals Finish or the clock is unset. A wake
is not a new start: it must not extend the finish, restart the cycle, or revive a
canceled, disabled, or thermally stopped manual run. Calendar-driven launches retain
their existing scheduling behavior.

`EVT` also includes additive diagnostic lines in the normal received serial log:

```text
* Runtime: v=1 start=1789516800 finish=1789580208 onair=-180 sleep=1 enabled=1 commenced=1 manual=1 forever=0 day=3 days=3
* Button wake: v=1 count=1 at=1789547940
* Wake before: v=1 start=1789516800 finish=1789580208 onair=-180 sleep=2 enabled=1 commenced=1 manual=1 forever=0 day=3 days=3
* Wake after: v=1 start=1789516800 finish=1789580208 onair=-180 sleep=1 enabled=1 commenced=1 manual=1 forever=0 day=3 days=3
```

`Runtime` is the current event-engine state, separately from session history.
`Wake before` and `Wake after` capture event restoration at the end of the most
recent successful button-wake authorization, not the physical button edge.
`count` counts authorized button wakes since reset (saturating at 4294967295);
zero means no retained wake and omits both snapshots. `at` uses the same device
wall-clock encoding as session records, or zero when the clock is unset.

`onair` is the signed seconds countdown: negative before a transmit slot, positive
inside a slot, zero at its boundary. It does not establish measured RF output.
`sleep` is 0 waiting for scheduled start, 1 active/after-event mode, 2 between
transmissions, 3 indefinite sleep, or 4 forced power-off. `enabled` and `commenced`
are event-engine flags; `manual` identifies a user-launched run, and `forever`
identifies a run without a timed finish. `day` is the saved calendar's zero-based
progress index and `days` its configured count; exhausted calendar days do not
invalidate a separately launched manual run.

The last wake snapshots are bounded RAM diagnostics, lost on reset, and are only
printed when `EVT` is requested. Capturing them adds no EEPROM writes, ADC samples,
serial traffic, or extra wake-ups. Normal timer and serial wake paths are unchanged.
The existing `just test` session-runtime test now exercises the production calendar
and wake helpers together, with manual and scheduled controls, cancellation,
temperature stops, repeated wakes, and exact finish boundaries. Actual RF and
physical button timing remain bench checks.

## Button cancellation and expired schedules

A new synchronized manual run uses a saved duration only while a valid current or
future calendar window remains. An unset, invalid, or exhausted schedule cannot
limit that run: it runs until explicitly canceled, aligned to the clock when the
clock is valid, or relative to the manual start otherwise. Saved settings are not
erased. An already-running manual event keeps its original finish across wakes.

| Button operation | Result |
| --- | --- |
| Hold while asleep, or while awake with LEDs timed out | Authorize wake or revive LEDs; release before issuing another command. |
| Awake hold during an ordinary active calendar event, on-air or off-air | Cancel today's event, advance to the next configured day if present, and sleep. |
| Awake hold before a future event | Sleep with the schedule armed. |
| Awake hold during a temporary carrier or Morse demo | Stop the test, restore the calendar phase, and sleep without canceling today or explicitly advancing the day. |
| Three presses during an active calendar event, including a temporary test | Cancel today and advance to the next configured day if present. |
| Three presses before a future event | Clear temporary activity and re-arm the schedule. |
| Three presses during a manual run with no remaining schedule | Stop the manual run. |

The hold's temporary-test or future-schedule intent is captured at its first
debounced edge. A test expiring, or a scheduled start arriving, while the switch
remains closed must not convert that hold into a day cancellation. Normal calendar
expiry still applies: a test stopped at today's finish may reveal tomorrow's
window, but must not skip it. Restoring an active schedule also retains its
transmit phase; if its slot is already on-air or imminent, the requested sleep may
be brief and the RTC will wake the unit for that slot.

Single-press carrier/demo behavior remains unchanged. In particular, before a
future event the carrier, Morse demonstration, and return-to-schedule sequence
continues to use the existing button and timeout behavior.

`EVT` now also reports the last processed cancellation or scheduled-sleep command:

```text
* Button action: v=1 count=4 at=1789547940 action=1 day_before=0 day_after=0
```

Actions are 1 stop temporary test, 2 cancel current day, 3 cancel manual run,
4 re-arm schedule, and 5 sleep with schedule preserved. `count` saturates at
4294967295 and counts these recorded actions since reset; it is not a raw press
counter. `at` uses device wall-clock time, or zero with an unset clock. The day
indices are zero-based. The line is omitted until an action is recorded. Like the
wake snapshots, this is RAM-only, printed on request into the normal received
serial log, with no added EEPROM writes or periodic telemetry.

The production button detector, long-hold and three-press handlers, manual-start
setup, event activation, and off-air sleep decision are exercised by the host
runtime tests. Coverage includes on-air/off-air cancellation, last-day cancellation,
temporary-test expiry while held, a scheduled start while held, release requirements,
thermal blocking, repeated wakes, and expired/absent/invalid clock settings.
Hardware I/O is stubbed in these checks; physical debounce, standby current, LED
behavior, and RF output still require bench validation.

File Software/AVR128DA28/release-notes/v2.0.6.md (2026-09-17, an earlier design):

# SignalSlinger 2.0.6

SignalSlinger 2.0.6 improves manual-event continuity, button behavior and serial reliability. Packages are available for HW 3.4 and HW 3.5. Use SerialSlinger 2.0.21 for the accompanying clone-template, running-event read and log-viewer fixes.

## User-visible changes

- Manually started events retain their running state and transmission timing across sleep and authorized button wake. Waking the unit no longer replaces a manual run with an expired saved schedule.
- An expired, invalid or unset schedule no longer limits a newly started manual run to an old event duration. The run continues until canceled, aligned to the clock when valid and to the manual start when the clock is unset.
- A long hold while asleep wakes the unit. Once awake with LEDs active, a long hold during an ordinary active timed event cancels the current day, advances to the next scheduled day if present, and sleeps. A hold before a future event sleeps with the schedule armed.
- Long holds during temporary carrier or Morse demonstrations cancel the temporary activity and return to the schedule without canceling the current day. A temporary test expiring, or an event starting while the button remains held, cannot change that hold into an unintended day cancellation.
- Three presses clear temporary activity before a future event, cancel the current day during an active timed event, and stop an indefinite manual run.
- Normally completed manual events report Event completed instead of misleading configuration/interruption errors. Genuine interruptions remain distinguishable.
- The fast green low-battery indication now requires a low internal battery and external voltage below 6.0 V, independently of charging state.

## Stability and reliability

- Starting an indefinite manual run without a valid clock now marks its immediate transmit phase started before enabling timer processing, preventing an interrupt from replacing that phase with the fox's scheduled offset.

- EEPROM readiness checks before reads and between multi-byte writes let serial reception and timer interrupts continue during persistence operations. Reproductions that previously caused serial overruns and roughly 11 ms timer-service gaps passed with no errors and approximately 2 ms service intervals after the fix.
- Corrupted serial commands are discarded through their line terminator rather than executing a truncated setting; bounded receive-error counters aid diagnosis.
- Automated hardware support exercises the ordinary button detector and scheduler, captures bounded timer/state traces, and reports authorized button-wake snapshots. Optional latency instrumentation is excluded from normal release builds.
- Host checks cover EEPROM representations, interrupt-state preservation, simulated power-cut recovery, damaged serial input, button timing boundaries, manual/scheduled behavior, thermal protection and ADC/battery behavior. EEPROM layout, checksums and journal commit ordering remain compatible.

### Hardware validation scope

The preceding development build passed all 24 automated HW 3.5 behavior cases and 21 continuous-traffic captures, including actual timed sleep/wake cycles, with zero receive errors in the final verification runs. The initial test-runner startup/wake synchronization error was corrected and the complete suite rerun. Both board revisions build without warnings. Release-image programming and readback evidence is recorded separately in the release checklist.

Physical button wake/contact bounce, external RF/optical/current measurements, actual supply-interruption recovery, physical HW 3.4 programming and full hardware rollback have not been established by those automated checks. These coverage limits are retained explicitly.

## Release files

- `SignalSlinger-Update-v2.0.6-HW-3.4.hex`
- `SignalSlinger-v2.0.6-HW-3.4-Release-Files.zip`
- `SignalSlinger-Update-v2.0.6-HW-3.5.hex`
- `SignalSlinger-v2.0.6-HW-3.5-Release-Files.zip`

## Full changelog

[Compare v2.0.5...v2.0.6](https://github.com/OpenARDF/SignalSlinger/compare/v2.0.5...v2.0.6)

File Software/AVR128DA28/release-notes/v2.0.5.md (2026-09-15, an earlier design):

# SignalSlinger 2.0.5

SignalSlinger 2.0.5 corrects temperature and voltage sampling and improves external-battery feedback while the unit is awake. Packages are available for HW 3.4 and HW 3.5.

## User-visible changes

- Temperature queries now allow the sensor and ADC to settle correctly. This fixes falsely elevated readings during repeated SerialSlinger refreshes and the resulting fan stopping and restarting every few seconds.
- External-battery LED feedback updates more promptly while the unit is awake. Brief voltage checks detect a connected battery when managed external power is off; an intentionally disabled power output no longer replaces the last measured battery voltage with zero.
- The existing sleep schedule, fan temperature thresholds, and thermal-protection settings are preserved.

## Stability and reliability

- All five supported ADC inputs use the corrected channel-selection and startup sequence, including the first measurement after charging or standby initialization.
- Foreground temperature and voltage readings share one conversion helper. It clears stale completion flags, bounds the wait for a fresh result, and shuts the ADC down on timeout so later measurements can recover.
- Regression checks cover channel changes, pre-enabled startup, stale results, completion at the timeout boundary, stalled conversions, recovery, and free-running to single-shot transitions. Battery-feedback checks retain the sleep and shared-output boundaries.

### Hardware validation scope

The ADC corrections were programmed and checked on a HW 3.5 unit, including live temperature and battery readings; the reported fan cycling stopped. Those checks used the development build preceding the release version change. Full physical HW 3.4 validation, interrupted-update recovery, and hardware rollback have not been completed for this release.

## Release files

- `SignalSlinger-Update-v2.0.5-HW-3.4.hex`
- `SignalSlinger-v2.0.5-HW-3.4-Release-Files.zip`
- `SignalSlinger-Update-v2.0.5-HW-3.5.hex`
- `SignalSlinger-v2.0.5-HW-3.5-Release-Files.zip`

## Full changelog

[Compare v2.0.4...v2.0.5](https://github.com/OpenARDF/SignalSlinger/compare/v2.0.4...v2.0.5)

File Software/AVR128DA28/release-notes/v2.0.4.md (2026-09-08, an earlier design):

# SignalSlinger 2.0.4

SignalSlinger 2.0.4 is the next firmware release after v2.0.3.

## User-visible changes

- Thermal shutdown is enabled by default at 65 C, including on older devices without a saved choice. Temperature reporting, maximum-temperature tracking, and fan control remain active.
- Operators can explicitly disable or enable thermal shutdown and select a trip threshold from 30 C through 85 C in a compatible SerialSlinger build.

## Stability and reliability

- The configured threshold is now the actual trip point for every battery configuration, with a uniform 5 C clear hysteresis.
- The enable choice uses the existing EEPROM padding byte, preserving all established configuration offsets and migrating legacy, erased, or unknown values to enabled at 65 C. Explicit choices saved by this firmware remain in effect.

- An overheated scheduled session pauses with RF off and resumes in its original time window after cooling by 5 C. Cooling does not extend the finish time or consume a later day.
- Later scheduled days survive a thermal interruption. Remaining days describe calendar windows, not successful runs.
- EVT reports device-recorded starts, pauses, resumes and stops, including reason, device time (when known), temperature and threshold. A bounded EEPROM journal retains recent history across resets and rejects incomplete writes.
- A finish after a pause is reported as interrupted or finished with interruptions, never uninterrupted completion. Power loss/reset is recorded with an unknown stop time rather than an invented timestamp.
- Missing or stale temperature readings block RF until a valid safe reading arrives. Manual starts remain subject to the same RF protection.

## Installation and field testing

Use SerialSlinger 2.0.20 for the matching session-history display and delayed multi-day schedule fixes. In SerialSlinger, select the firmware update for the transmitter hardware revision (HW 3.4 or HW 3.5). The matching ZIP includes the recovery files and programming instructions; read its README before recovery or first-install programming.

After updating, reconnect and confirm firmware 2.0.4, temperature protection enabled, and a 65 C shutdown threshold. Read back the requested start date, daily finish time, and three scheduled days. Thermal recovery preserves the original finish time; it does not add extra operating time after cooling. Save SerialSlinger session logs after the field test.

Automated checks cover thermal recovery, scheduling, EEPROM history, and both hardware builds. Physical programming, RF output, temperature response, and recovery on representative HW 3.4 and HW 3.5 units remain unverified for this candidate.

## Release files

- `SignalSlinger-Update-v2.0.4-HW-3.4.hex`
- `SignalSlinger-v2.0.4-HW-3.4-Release-Files.zip`
- `SignalSlinger-Update-v2.0.4-HW-3.5.hex`
- `SignalSlinger-v2.0.4-HW-3.5-Release-Files.zip`

## Full changelog

[Compare v2.0.3...v2.0.4](https://github.com/OpenARDF/SignalSlinger/compare/v2.0.3...v2.0.4)

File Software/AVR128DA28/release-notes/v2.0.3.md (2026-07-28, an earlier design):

# SignalSlinger 2.0.3

SignalSlinger 2.0.3 adds a stable device identity for safer transmitter
management and strengthens the firmware release process for both supported
hardware revisions.

## User-visible changes

- The firmware now reports the AVR's factory-programmed device ID as a
  32-character `uid` value in `INF` status output. The ID remains stable across
  firmware updates and settings changes, allowing compatible tools such as
  SerialSlinger to recognize when a different transmitter is connected through
  the same USB serial adapter. Older firmware remains compatible and simply
  omits this line.
- The project README now links directly to the available SignalSlinger
  transmitter kit and its current ordering information.

## Stability and reliability

- Stable device identity improves update target verification and reduces the
  risk of silently treating a replacement transmitter as the previously loaded
  unit.
- Release builds for HW-3.4 and HW-3.5 now use pinned compiler and device-pack
  versions on macOS, with byte-for-byte repeatability checks for the normal
  application, bootloader-relocated application, bootloader, and complete
  release packages. Package contents, checksums, flash geometry, compiler
  warnings, and source revision are independently validated before
  publication.
- Bootloader behavior and its protocol are unchanged in this release.

## Release files

- `SignalSlinger-Update-v2.0.3-HW-3.4.hex`
- `SignalSlinger-v2.0.3-HW-3.4-Release-Files.zip`
- `SignalSlinger-Update-v2.0.3-HW-3.5.hex`
- `SignalSlinger-v2.0.3-HW-3.5-Release-Files.zip`

## Full changelog

[Compare v2.0.2...v2.0.3](https://github.com/OpenARDF/SignalSlinger/compare/v2.0.2...v2.0.3)

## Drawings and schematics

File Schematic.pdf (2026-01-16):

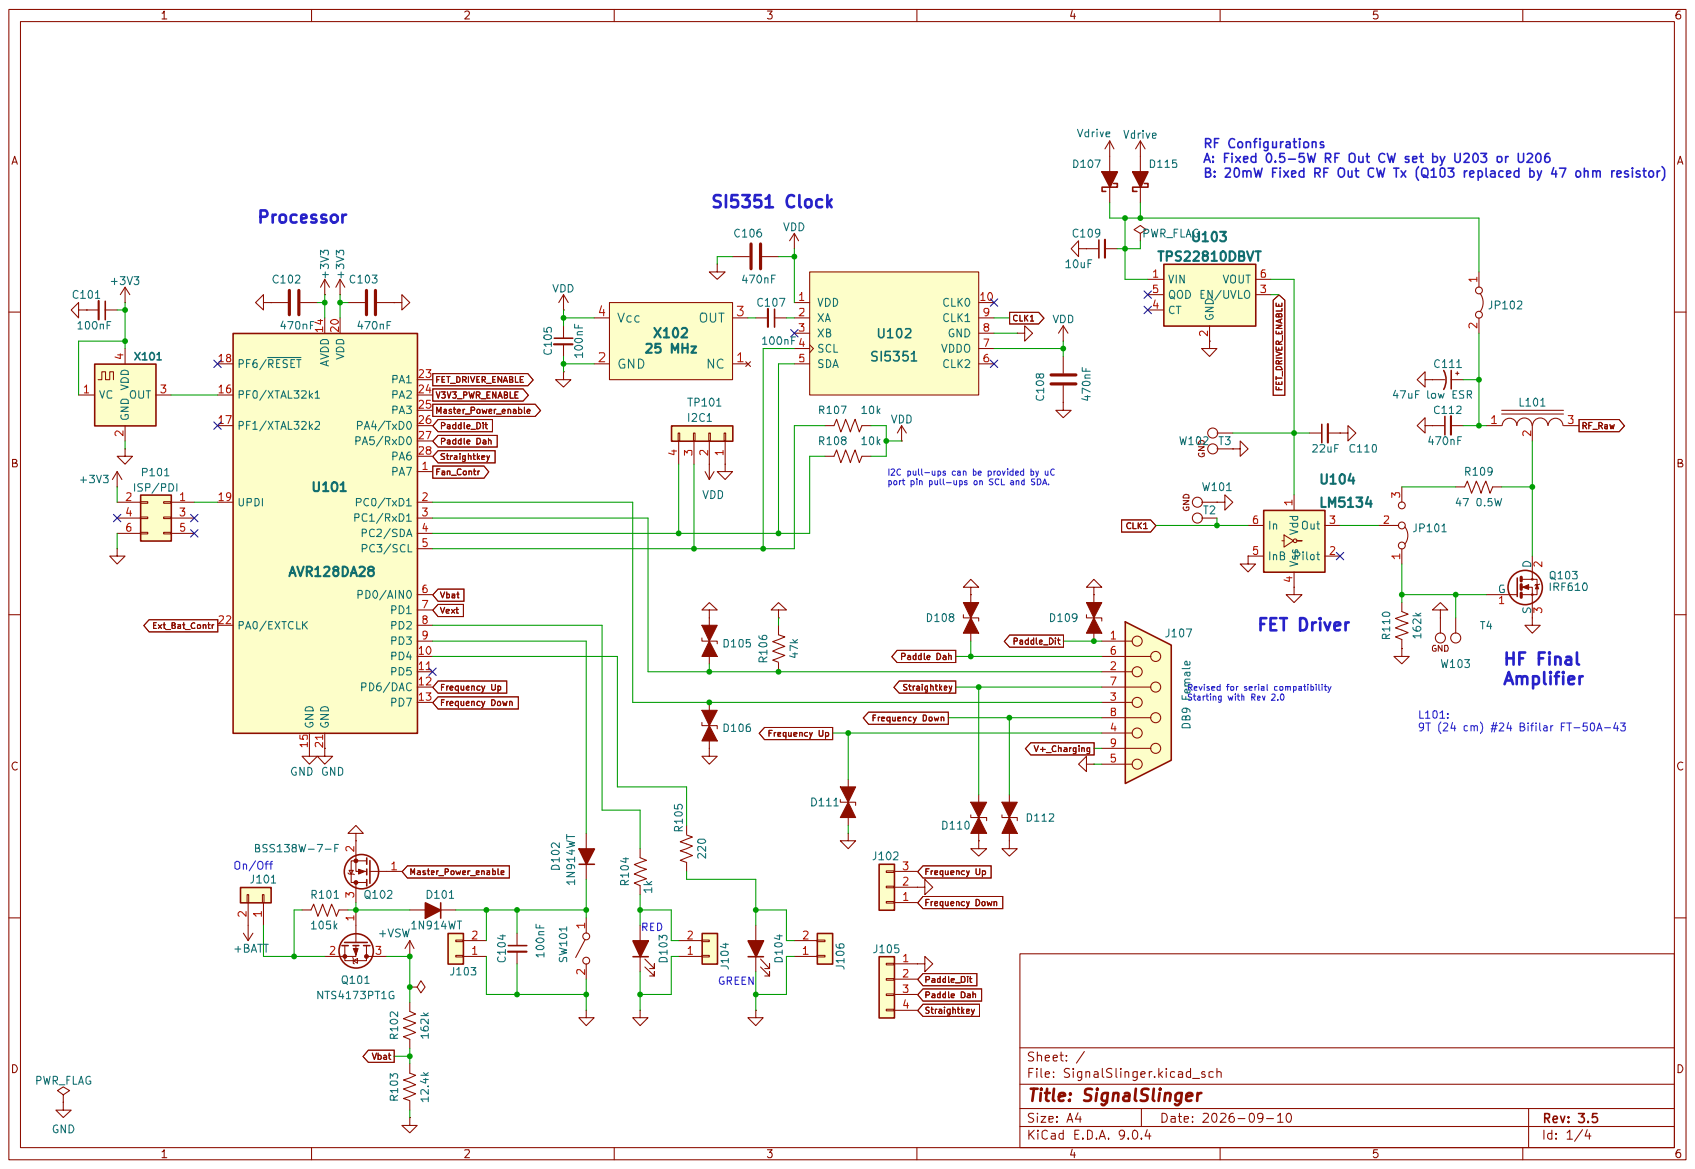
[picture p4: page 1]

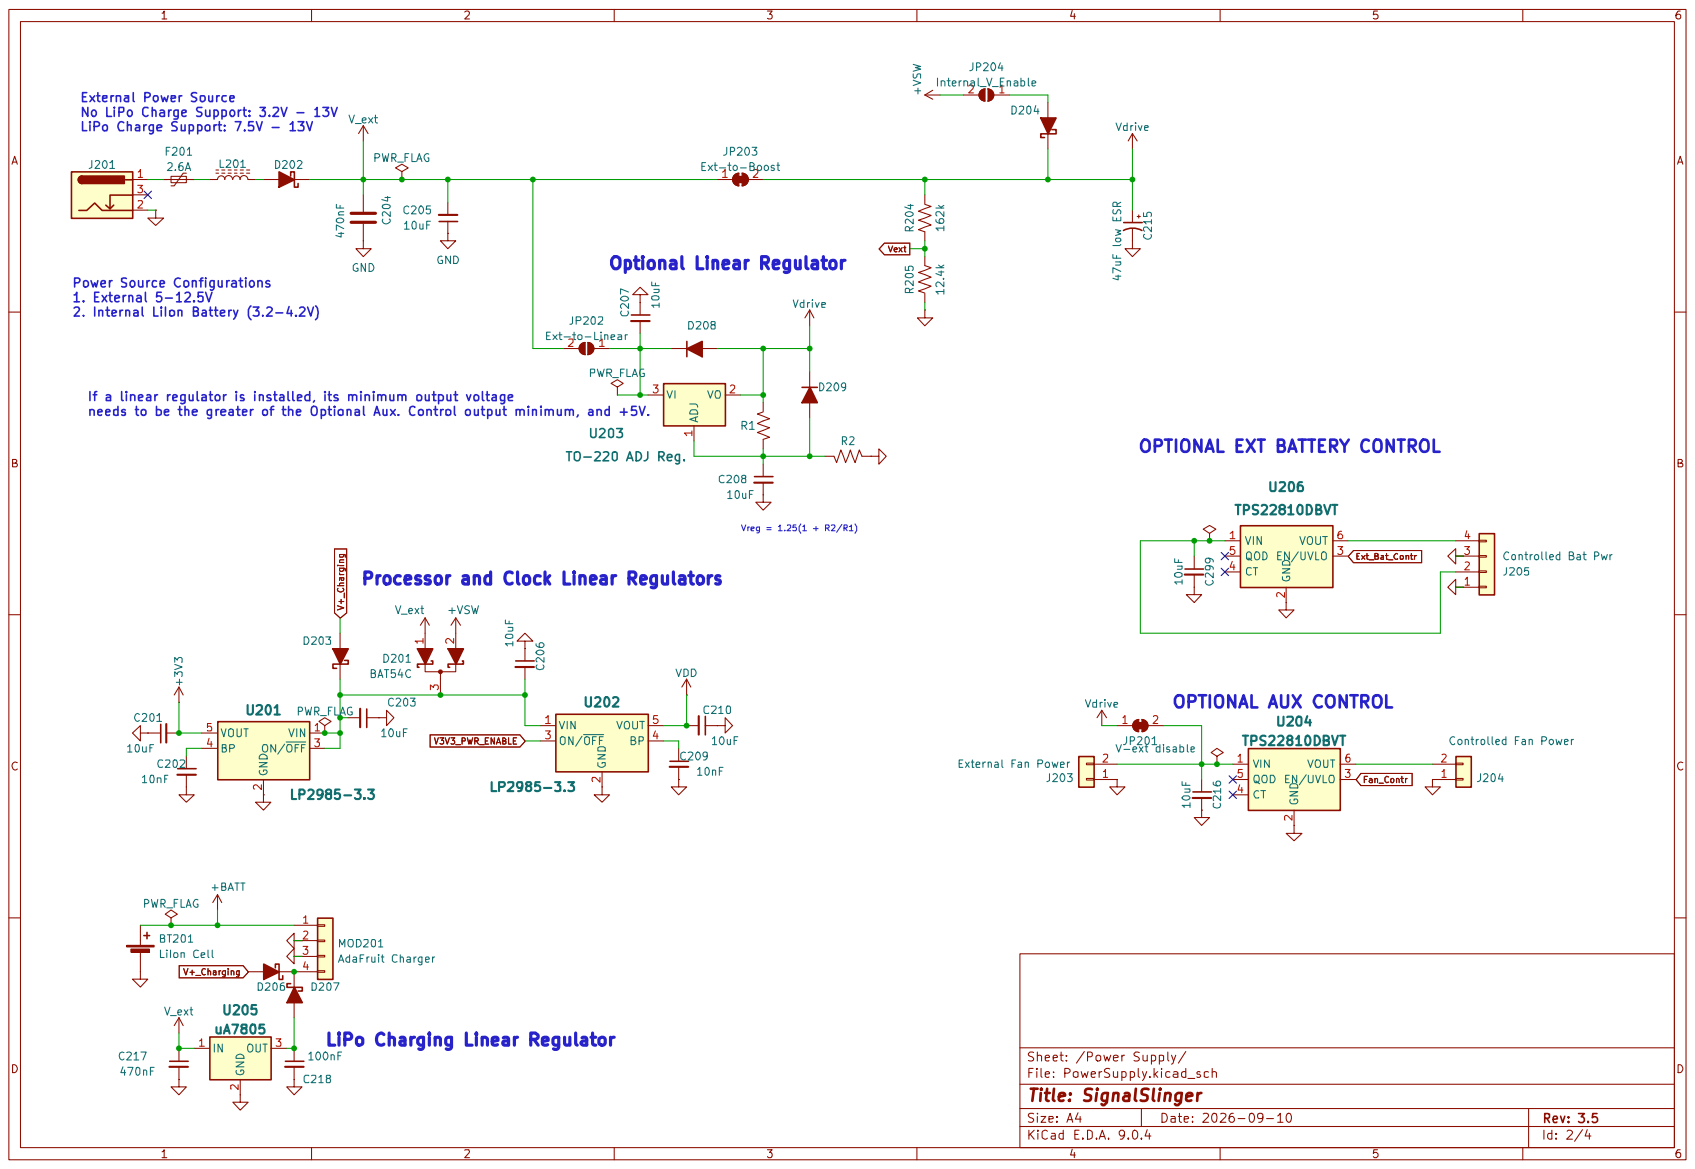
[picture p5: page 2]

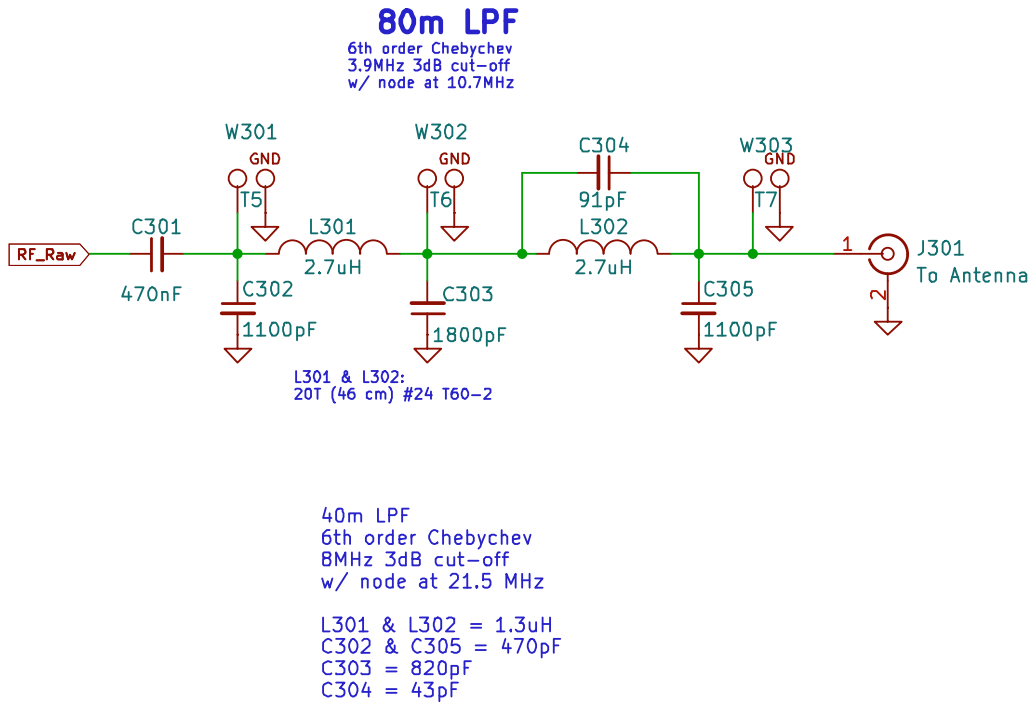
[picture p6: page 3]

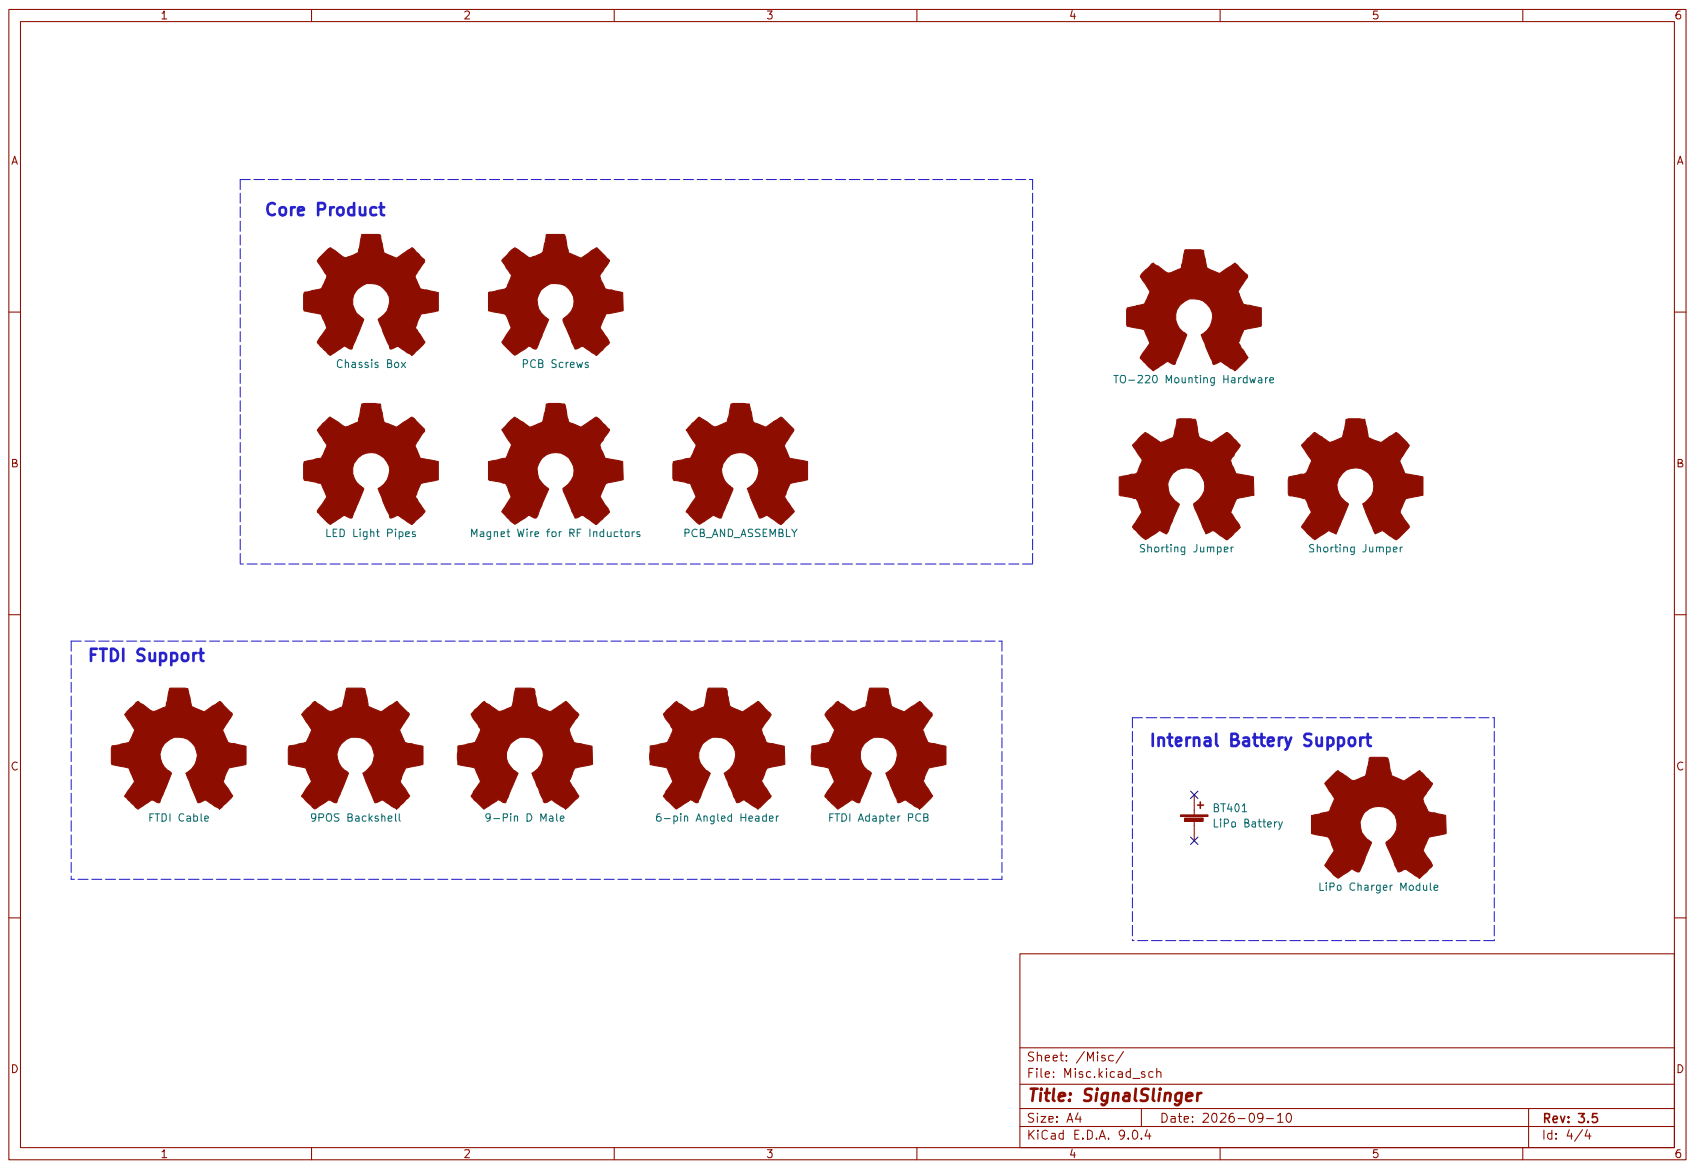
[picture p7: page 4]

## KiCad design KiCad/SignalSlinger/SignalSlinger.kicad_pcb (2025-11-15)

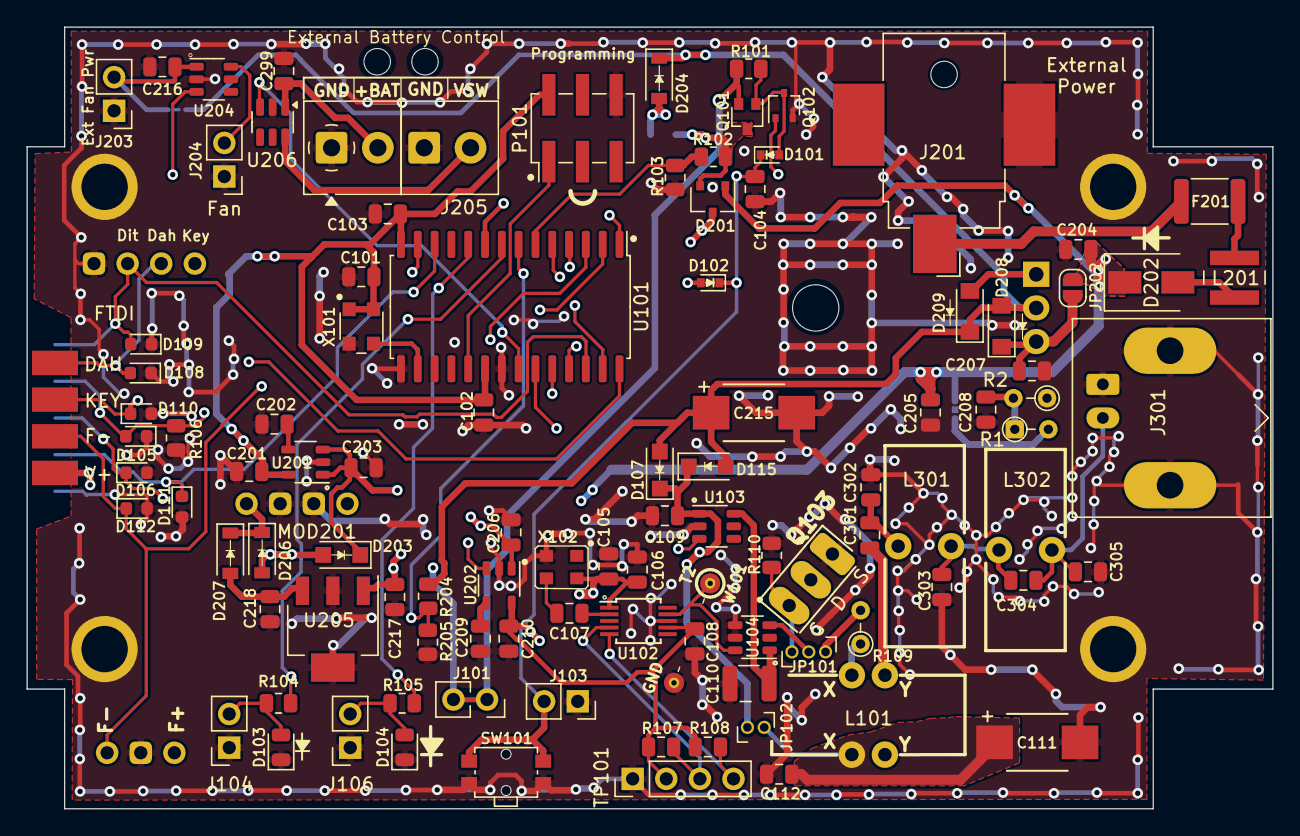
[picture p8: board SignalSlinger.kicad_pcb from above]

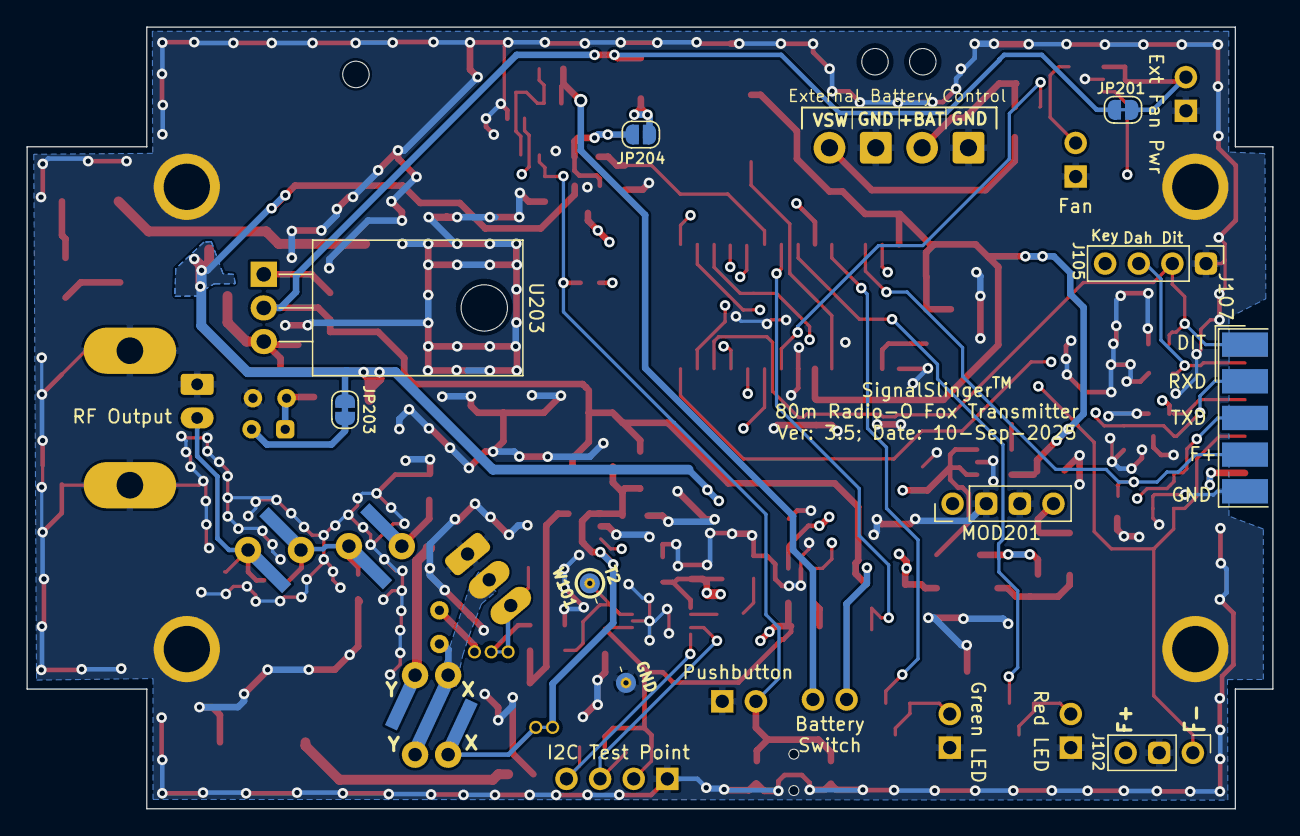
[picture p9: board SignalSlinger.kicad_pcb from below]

Board: 4 copper layers, 94.1 x 59.1 mm, 110 parts (8 on the bottom side), 63 nets.

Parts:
C101, C104, C105, C107, C218: 100nF; C_0805_2012Metric
C102, C103, C106, C108, C112, C204, C217, C301: 470nF; C_0805_2012Metric
C109, C201, C203, C205, C206, C207, C208, C210, C216, C299: 10uF; C_0805_2012Metric
C110: 22uF; C_1210_3225Metric
C111, C215: 47uF low ESR; C_2917
C202, C209: 10nF; C_0805_2012Metric
C302, C305: 1100pF; C_0805_2012Metric
C303: 1800pF; C_0805_2012Metric
C304: 91pF; C_0805_2012Metric
D101, D102: 1N914WT; D_SOD-523
D103: Red LED; LED_0805_2012Metric
D104: Green LED; LED_0805_2012Metric
D105, D106, D108, D109, D110, D111, D112: ESD9B5.0ST5G_1; D_0603_1608Metric
D107, D115, D203, D204, D206, D207: Schottky Diode; D_SOD-123FL
D201: BAT54C; SC-59
D202: B330A Schottky Diode; D_SMB
D208, D209: 1N4001; D_SOD-123F
F201: 2.6A; Fuse_1812_4532Metric
J101, J103, J104, J106: Conn_01x02; PinSocket_1x02_P2.54mm_Vertical
J102: Conn_01x03; PinHeader_1x03_P2.54mm_Vertical
J105: Conn_01x04; PinHeader_1x04_P2.54mm_Vertical
J107: DB9 Female; DSUB-9_Female_EdgeMount_P2.77mm
J201: Barrel_Jack_Switch; BarrelJack_CUI_PJ-036AH-SMT_Horizontal
J203: External Fan Power; PinHeader_1x02_P2.54mm_Vertical
J204: Controlled Fan Power; PinHeader_1x02_P2.54mm_Vertical
J205: Controlled Bat Pwr; TerminalBlock_4Ucon_1x02_P3.50mm_Horizontal
J301: To Antenna; BNC_Amphenol_B6252HB-NPP3G-50_Horizontal
JP101: Jumper_3_Bridged12; Jumper_THT_1x03_Bridged12_P1.27mm_Vertical
JP102: Jumper_2_Bridged; Jumper_THT_1x02_P1.27mm_Vertical
JP201: V-ext disable; SolderJumper-2_P1.3mm_Bridged_RoundedPad1.0x1.5mm
JP202: Ext-to-Linear; SolderJumper-2_P1.3mm_Open_RoundedPad1.0x1.5mm
JP203: Ext-to-Boost; SolderJumper-2_P1.3mm_Bridged_RoundedPad1.0x1.5mm
JP204: Internal_V_Enable; SolderJumper-2_P1.3mm_Open_RoundedPad1.0x1.5mm
L101: 9T #24 Bifilar T50-43; Toroid_T-50A_TH_BF_CT_Vertical
L201: 2.2uH; WPN4020H2R2MT
L301: 2.7uH; Toroid_T-60_2TH_Vertical
L302: 2.7uH; Toroid_T-60_2TH_Vertical2
MOD201: AdaFruit Charger; PinHeader_1x04_P2.54mm_Vertical
P101: ISP/PDI; PinHeader_2x03_P2.54mm_Vertical_SMD
Q101: NTS4173PT1G; SOT-323_SC-70
Q102: BSS138W-7-F; SOT-323_SC-70
Q103: IRF610; TO-220_Neutral123_Vertical_LargePads
R1, R2: TBD; R_Axial_DIN0204_L3.6mm_D1.6mm_P2.54mm_Vertical
R101: 105k; R_0805_2012Metric
R102, R110, R204: 162k; R_0805_2012Metric
R103, R205: 12.4k; R_0805_2012Metric
R104: 1k; R_0805_2012Metric
R105: 220; R_0805_2012Metric
R106: 47k; R_0805_2012Metric
R107, R108: 10k; C_0805_2012Metric
R109: 47 0.5W; R_Axial_DIN0204_L3.6mm_D1.6mm_P2.54mm_Vertical
SW101: SW_SPST; SW_SPST_TL1014BF160QG
TP101: I2C1; PinHeader_1x04_P2.54mm_Vertical
U101: AVR128DA28; SOIC-28W_7.5x17.9mm_P1.27mm
U102: SI5351; MSOP-10_3x3mm_P0.5mm
U103, U204, U206: TPS22810DBVT; SOT-23-6
U104: LM5134; SOT-23-6-LM5134
U201, U202: LP2985-3.3; SOT-23-5
U203: TO-220 ADJ Reg.; TO-220-3_Horizontal_TabDown
U205: uA7805; SOT-223-4
W101: T2; Measurement_Point_ScopeProbe_Round-SMD-2sides-Pad_Small
X101: ECS-327TXO-30-TR; Oscillator_SMD_ECS_327TXO
X102: 25 MHz; Crystal_SMD_TXETCLSANF-4Pin

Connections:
+3V3: C101.1, C102.1, C103.2, C201.2, P101.2, U101.14 (AVDD), U101.20 (VDD), U201.5 (VOUT), X101.1 (VC), X101.4 (VDD)
+BATT: J101.2, MOD201.1
+VSW: D201.2 (K), JP204.2 (B), Q101.3 (D), R102.2
CLK1: U102.9 (CLK1), U104.6 (In), W101.1
Ext_Bat_Contr: U101.22 (PA0/EXTCLK), U206.3 (EN/UVLO)
FET_DRIVER_ENABLE: U101.23 (PA1), U103.3 (EN/UVLO)
Fan_Contr: U101.1 (PA7), U204.3 (EN/UVLO)
Frequency Down: D112.1 (A1), J102.1, J107.8, U101.13 (PD7)
Frequency Up: D111.1 (A1), J102.3, J107.4, U101.12 (PD6/DAC)
GND: C101.2, C102.2, C103.1, C104.2, C105.2, C106.2, C108.2, C109.1, C110.2, C111.2, C112.1, C201.1, C202.2, C203.1, C204.1, C205.1, C206.1, C207.1, C208.2, C209.2, C210.1, C215.2, C216.2, C217.2, C218.2, C299.2, C302.2, C303.1, C305.2, D103.1 (K), D104.1 (K), D105.1 (A1), D106.2 (A2), D108.1 (A1), D109.1 (A1), D110.2 (A2), D111.2 (A2), D112.2 (A2), J102.2, J103.1, J104.1, J105.1, J106.1, J107.5, J201.2, J203.1, J204.1, J205.1, J205.3, J301.2 (Ext), MOD201.2, MOD201.3, P101.6, Q102.2 (S), Q103.3 (S), R2.1, R103.1, R106.2, R110.1, R205.1, SW101.2 (B), TP101.1, U101.15 (GND), U101.21 (GND), U102.8 (GND), U103.2 (GND), U104.4 (Vss), U104.5 (InB), U201.2 (GND), U202.2 (GND), U204.2 (GND), U205.2 (GND), U206.2 (GND), W101.2 (GND), X101.2 (GND), X102.2 (GND)
Master_Power_enable: Q102.1 (G), U101.25 (PA3)
unnamed: C301.2, C302.1, L301.1
unnamed: C303.2, C304.2, L301.2, L302.1
unnamed: D101.2 (A), Q101.1 (G), Q102.3 (D), R101.1
unnamed: C104.1, D101.1 (K), D102.1 (K), J103.2, SW101.1 (A)
unnamed: D102.2 (A), U101.9 (PD3)
unnamed: D103.2 (A), J104.2, R104.1
unnamed: D104.2 (A), J106.2, R105.1
unnamed: D105.2 (A2), J107.2, R106.1, U101.3 (PC1/RxD1)
unnamed: D106.1 (A1), J107.3, U101.2 (PC0/TxD1)
unnamed: C109.2, D107.1 (K), D115.1 (K), JP102.1 (A), U103.1 (VIN)
unnamed: C203.2, C206.2, D201.3 (A), D203.1 (K), U201.1 (VIN), U201.3 (ON/~OFF), U202.1 (VIN)
unnamed: D202.2 (A), L201.2
unnamed: D204.2 (A), JP204.1 (A)
unnamed: D206.1 (K), D207.1 (K), MOD201.4
unnamed: C218.1, D207.2 (A), U205.3 (OUT)
unnamed: C207.2, D208.1 (K), JP202.1 (A), U203.3 (VI)
unnamed: C208.1, D209.2 (A), R1.1, R2.2, U203.1 (ADJ)
unnamed: F201.1, L201.1
unnamed: F201.2, J201.1
unnamed: J101.1, Q101.2 (S), R101.2
unnamed: C216.1, J203.2, JP201.2 (B), U204.1 (VIN)
unnamed: J204.2, U204.6 (VOUT)
unnamed: C299.1, J205.2, U206.1 (VIN)
unnamed: J205.4, U206.6 (VOUT)
unnamed: C304.1, C305.1, J301.1 (In), L302.2
unnamed: JP101.1 (A), Q103.1 (G), R110.2
unnamed: JP101.3 (B), R109.2
unnamed: JP101.2 (C), U104.3 (Out)
unnamed: C111.1, C112.2, JP102.2 (B), L101.1
unnamed: L101.2 (TAP), Q103.2 (D), R109.1
unnamed: P101.1, U101.19 (UPDI)
unnamed: R107.1, TP101.3, U101.5 (PC3/SCL), U102.4 (SCL)
unnamed: R108.1, TP101.4, U101.4 (PC2/SDA), U102.5 (SDA)
unnamed: R104.2, U101.8 (PD2)
unnamed: R105.2, U101.10 (PD4)
unnamed: U101.16 (PF0/XTAL32k1), X101.3 (OUT)
unnamed: C107.1, U102.2 (XA)
unnamed: C110.1, U103.6 (VOUT), U104.1 (Vdd)
unnamed: C202.1, U201.4 (BP)
unnamed: C209.1, U202.4 (BP)
unnamed: C107.2, X102.3 (OUT)
Paddle Dah: D108.2 (A2), J105.3, J107.6, U101.27 (PA5/RxD0)
Paddle_Dit: D109.2 (A2), J105.2, J107.1, U101.26 (PA4/TxD0)
RF_Raw: C301.1, L101.3
Straightkey: D110.1 (A1), J105.4, J107.7, U101.28 (PA6)
V3V3_PWR_ENABLE: U101.24 (PA2), U202.3 (ON/~OFF)
V+_Charging: D203.2 (A), D206.2 (A), J107.9
VDD: C105.1, C106.1, C108.1, C210.2, R107.2, R108.2, TP101.2, U102.1 (VDD), U102.7 (VDDO), U202.5 (VOUT), X102.4 (Vcc)
V_ext: C204.2, C205.2, C217.1, D201.1 (K), D202.1 (K), JP202.2 (B), JP203.1 (A), U205.1 (IN)
Vbat: R102.1, R103.2, U101.6 (PD0/AIN0)
Vdrive: C215.1, D107.2 (A), D115.2 (A), D204.1 (K), D208.2 (A), D209.1 (K), JP201.1 (A), JP203.2 (B), R1.2, R204.2, U203.2 (VO)
Vext: R204.1, R205.2, U101.7 (PD1)

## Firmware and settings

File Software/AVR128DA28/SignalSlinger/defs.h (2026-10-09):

/**********************************************************************************************
 * Copyright (c) 2026 Digital Confections LLC
 *
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
 **********************************************************************************************/

/*
 * Core firmware-wide definitions and constants.
 *
 * This header collects the product identity strings, feature toggles, shared
 * numeric limits, default persisted settings, and small enums that are used
 * across many modules.
 *
 * Behavior-specific logic should stay in feature modules; this file is meant to
 * provide the shared vocabulary those modules rely on.
 */

#ifndef DEFS_H
#define DEFS_H

#ifndef F_CPU
#define F_CPU 24000000UL /* gets declared in makefile */
#endif

#include <avr/io.h>
#include <avr/interrupt.h>
#include <stdint.h>

/******************************************************
 * Set the text that gets displayed to the user */
#define SW_REVISION "2.0.7"
#if !defined(HW_TARGET_3_4) && !defined(HW_TARGET_3_5)
// #define HW_TARGET_3_4
#define HW_TARGET_3_5
#endif

#if defined(HW_TARGET_3_4) && defined(HW_TARGET_3_5)
#error "Select exactly one SignalSlinger hardware target"
#endif

// #define TRANQUILIZE_WATCHDOG

#define PRODUCT_NAME_SHORT "SignalSlinger"
#define PRODUCT_NAME_LONG "SignalSlinger 80m Radio Orienteering Transmitter"

/* Caution: Do not enable test software build flag for releasable software */
// #define TEST_MODE_SOFTWARE /* Do not define on releasable software */
#ifdef TEST_MODE_SOFTWARE
#define TEXT_TEST_SOFTWARE_NOTICE_TXT (char *)"\n* TEST SOFTWARE: Do not distribute! \n* Some commands disabled.\n\n"
#undef SW_REVISION
#define SW_REVISION "*** TEST SOFTWARE ***"
#endif

/*******************************************************/

/******************************************************
 * Include only the necessary hardware and software support */
#define INCLUDE_SI5351_SUPPORT true // Silicon Labs Programmable Clock
#define DATE_STRING_SUPPORT_ENABLED

/* Select the high-level sleep behavior the power-management code should enter. */
typedef enum
{
	SLEEP_UNTIL_START_TIME,
	SLEEP_AFTER_EVENT,
	SLEEP_UNTIL_NEXT_XMSN,
	SLEEP_FOREVER,
	SLEEP_POWER_OFF_OVERRIDE
} SleepType;

/* Select how the device should enunciate status or transmissions. */
typedef enum
{
	DO_NOT_ENUNCIATE,
	LED_AND_RF,
	LED_ONLY
} Enunciation_t;

#define ENUNCIATION_BLINK_WPM 8

/*******************************************************/

#ifndef null
#define null 0
#endif

#ifndef PI
#define PI 3.141592653589793
#endif

#ifndef MINUTE
#define MINUTE 60UL
#endif

#ifndef HOUR
#define HOUR 3600UL
#endif

#ifndef DAY
#define DAY 86400UL
#endif

#ifndef YEAR
#define YEAR 31536000UL
#endif

#ifndef UINT16_MAX
#define UINT16_MAX 0xFFFFU
#endif

#define MAXIMUM_NUM_OF_KEYPRESSES 9

/*******************************************************/
/*******************************************************
 * ADC Scale Factors */
/* Battery voltage should be read when +12V supply is enabled and all transmitters are fully powered off */
#define ADC_REF_VOLTAGE_mV 1100UL

#define ADC_MAX_VOLTAGE_MV 4200L     /* maximum voltage the ADC can read */
#define BATTERY_VOLTAGE_MAX_MV 4200L /* voltage at which the battery is considered to be fully charged */
#define BATTERY_DROP 320L            /* voltage drop between the battery terminals and the ADC input while powering the ESP8266 */
#define BATTERY_DROP_OFFSET (BATTERY_DROP * 1023L)
#define VBAT(x) (BATTERY_DROP + (x * ADC_MAX_VOLTAGE_MV) / 1023L)
#define BATTERY_PERCENTAGE(x, y) ((100L * ((x * ADC_MAX_VOLTAGE_MV + BATTERY_DROP_OFFSET) - (1023L * y))) / ((BATTERY_VOLTAGE_MAX_MV - y) * 1023L))

#define SUPPLY_VOLTAGE_MAX_MV 14100L
#define VSUPPLY(x) ((x * SUPPLY_VOLTAGE_MAX_MV) / 1023L)

#define PA_VOLTAGE_MAX_MV 14100L
#define VPA(x) ((x * PA_VOLTAGE_MAX_MV) / 1023L)

#define INT_BAT_PRESENT_VOLTAGE (0.5)
#define INT_BAT_CHARGE_THRESH_LOW_MIN (3.0)
#define INT_BAT_CHARGE_THRESH_LOW_MAX (4.1)
#define INT_BAT_CHARGE_THRES_HIGH (4.2)
#define EXT_BAT_CHARGE_SUPPORT_THRESH_LOW (8.5)
#define EXT_BAT_PRESENT_VOLTAGE (6.0)

#define EEPROM_THERMAL_SHUTDOWN_THRESHOLD_DEFAULT ((int8_t)65)
#define EEPROM_THERMAL_SHUTDOWN_ENABLED_DEFAULT true
#define EEPROM_PROCESSOR_MAX_EVER_TEMPERATURE_DEFAULT (0.)
#define THERMAL_SHUTDOWN_THRESHOLD_HYSTERESIS_C ((int8_t)5)
#define THERMAL_SHUTDOWN_THRESHOLD_MIN_C ((int8_t)30)
#define THERMAL_SHUTDOWN_THRESHOLD_MAX_C ((int8_t)85)

// #define FAN_TURN_ON_TEMP (45.)
// #define FAN_TURN_OFF_TEMP (40.)
#define FAN_TURN_ON_TEMP (35.)
#define FAN_TURN_OFF_TEMP (30.)

#define MINIMUM_VALID_TEMP (-20.)
#define MAXIMUM_VALID_TEMP (125.)

typedef uint16_t BatteryLevel; /* in milliVolts */

#define TEXT_BUFF_SIZE 50

/*******************************************************/

#ifndef SELECTIVELY_DISABLE_OPTIMIZATION
#define SELECTIVELY_DISABLE_OPTIMIZATION
#endif
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

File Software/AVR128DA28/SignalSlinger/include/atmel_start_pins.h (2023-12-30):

/*
 * Code generated from START.
 *
 * This file will be overwritten when reconfiguring your START project.
 * Please copy examples or other code you want to keep to a separate file
 * to avoid losing it when reconfiguring.
 */
#ifndef ATMEL_START_PINS_H_INCLUDED
#define ATMEL_START_PINS_H_INCLUDED

#include <port.h>

/************************************************************************************
PORTA Helper Functions
*************************************************************************************/

/**
 * \brief Set PA0 pull mode
 *
 * Configure pin to pull up, down or disable pull mode, supported pull
 * modes are defined by device used
 *
 * \param[in] pull_mode Pin pull mode
 */
static inline void PA0_set_pull_mode(const enum port_pull_mode pull_mode)
{
	PORTA_set_pin_pull_mode(0, pull_mode);
}

/**
 * \brief Set PA0 data direction
 *
 * Select if the pin data direction is input, output or disabled.
 * If disabled state is not possible, this function throws an assert.
 *
 * \param[in] direction PORT_DIR_IN  = Data direction in
 *                      PORT_DIR_OUT = Data direction out
 *                      PORT_DIR_OFF = Disables the pin
 *                      (low power state)
 */
static inline void PA0_set_dir(const enum port_dir dir)
{
	PORTA_set_pin_dir(0, dir);
}

/**
 * \brief Set PA0 input/sense configuration
 *
 * Enable/disable PA0 digital input buffer and pin change interrupt,
 * select pin interrupt edge/level sensing mode
 *
 * \param[in] isc PORT_ISC_INTDISABLE_gc    = Iterrupt disabled but input buffer enabled
 *                PORT_ISC_BOTHEDGES_gc     = Sense Both Edges
 *                PORT_ISC_RISING_gc        = Sense Rising Edge
 *                PORT_ISC_FALLING_gc       = Sense Falling Edge
 *                PORT_ISC_INPUT_DISABLE_gc = Digital Input Buffer disabled
 *                PORT_ISC_LEVEL_gc         = Sense low Level
 */
static inline void PA0_set_isc(const PORT_ISC_t isc)
{
	PORTA_pin_set_isc(0, isc);
}

/**
 * \brief Set PA0 inverted mode
 *
 * Enable or disable inverted I/O on a pin
 *
 * \param[in] inverted true  = I/O on PA0 is inverted
 *                     false = I/O on PA0 is not inverted
 */
static inline void PA0_set_inverted(const bool inverted)
{
	PORTA_pin_set_inverted(0, inverted);
}

/**
 * \brief Set PA0 level
 *
 * Sets output level on a pin
 *
 * \param[in] level true  = Pin level set to "high" state
 *                  false = Pin level set to "low" state
 */
static inline void PA0_set_level(const bool level)
{
	PORTA_set_pin_level(0, level);
}

/**
 * \brief Toggle output level on PA0
 *
 * Toggle the pin level
 */
static inline void PA0_toggle_level()
{
	PORTA_toggle_pin_level(0);
}

/**
 * \brief Get level on PA0
 *
 * Reads the level on a pin
 */
static inline bool PA0_get_level()
{
	return PORTA_get_pin_level(0);
}

/**
 * \brief Set PA1 pull mode
 *
 * Configure pin to pull up, down or disable pull mode, supported pull
 * modes are defined by device used
 *
 * \param[in] pull_mode Pin pull mode
 */
static inline void PA1_set_pull_mode(const enum port_pull_mode pull_mode)
{
	PORTA_set_pin_pull_mode(1, pull_mode);
}

/**
 * \brief Set PA1 data direction
 *
 * Select if the pin data direction is input, output or disabled.
 * If disabled state is not possible, this function throws an assert.
 *
 * \param[in] direction PORT_DIR_IN  = Data direction in
 *                      PORT_DIR_OUT = Data direction out
 *                      PORT_DIR_OFF = Disables the pin
 *                      (low power state)
 */
static inline void PA1_set_dir(const enum port_dir dir)
{
	PORTA_set_pin_dir(1, dir);
}

/**
 * \brief Set PA1 input/sense configuration
 *
 * Enable/disable PA1 digital input buffer and pin change interrupt,
 * select pin interrupt edge/level sensing mode
 *
 * \param[in] isc PORT_ISC_INTDISABLE_gc    = Iterrupt disabled but input buffer enabled
 *                PORT_ISC_BOTHEDGES_gc     = Sense Both Edges
 *                PORT_ISC_RISING_gc        = Sense Rising Edge
 *                PORT_ISC_FALLING_gc       = Sense Falling Edge
 *                PORT_ISC_INPUT_DISABLE_gc = Digital Input Buffer disabled
 *                PORT_ISC_LEVEL_gc         = Sense low Level
 */
static inline void PA1_set_isc(const PORT_ISC_t isc)
{
	PORTA_pin_set_isc(1, isc);
}

/**
 * \brief Set PA1 inverted mode
 *
 * Enable or disable inverted I/O on a pin
 *
 * \param[in] inverted true  = I/O on PA1 is inverted
 *                     false = I/O on PA1 is not inverted
 */
static inline void PA1_set_inverted(const bool inverted)
{
	PORTA_pin_set_inverted(1, inverted);
}

/**
 * \brief Set PA1 level
 *
 * Sets output level on a pin
 *
 * \param[in] level true  = Pin level set to "high" state
 *                  false = Pin level set to "low" state
 */
static inline void PA1_set_level(const bool level)
{
	PORTA_set_pin_level(1, level);
}

/**
 * \brief Toggle output level on PA1
 *
 * Toggle the pin level
 */
static inline void PA1_toggle_level()
{
	PORTA_toggle_pin_level(1);
}

/**
 * \brief Get level on PA1
 *
 * Reads the level on a pin
 */
static inline bool PA1_get_level()
{
	return PORTA_get_pin_level(1);
}







/**
 * \brief Set PA4 pull mode
 *
 * Configure pin to pull up, down or disable pull mode, supported pull
 * modes are defined by device used
 *
 * \param[in] pull_mode Pin pull mode
 */
static inline void PA4_set_pull_mode(const enum port_pull_mode pull_mode)
{
	PORTA_set_pin_pull_mode(4, pull_mode);
}

/**
 * \brief Set PA4 data direction
 *
 * Select if the pin data direction is input, output or disabled.
 * If disabled state is not possible, this function throws an assert.
 *
 * \param[in] direction PORT_DIR_IN  = Data direction in
 *                      PORT_DIR_OUT = Data direction out
 *                      PORT_DIR_OFF = Disables the pin
 *                      (low power state)
 */
static inline void PA4_set_dir(const enum port_dir dir)
{
	PORTA_set_pin_dir(4, dir);
}

/**
 * \brief Set PA4 input/sense configuration
 *
 * Enable/disable PA0 digital input buffer and pin change interrupt,
 * select pin interrupt edge/level sensing mode
 *
 * \param[in] isc PORT_ISC_INTDISABLE_gc    = Iterrupt disabled but input buffer enabled
 *                PORT_ISC_BOTHEDGES_gc     = Sense Both Edges
 *                PORT_ISC_RISING_gc        = Sense Rising Edge
 *                PORT_ISC_FALLING_gc       = Sense Falling Edge
 *                PORT_ISC_INPUT_DISABLE_gc = Digital Input Buffer disabled
 *                PORT_ISC_LEVEL_gc         = Sense low Level
 */
static inline void PA4_set_isc(const PORT_ISC_t isc)
{
	PORTA_pin_set_isc(4, isc);
}

/**
 * \brief Set PA4 inverted mode
 *
 * Enable or disable inverted I/O on a pin
 *
 * \param[in] inverted true  = I/O on PA0 is inverted
 *                     false = I/O on PA0 is not inverted
 */
static inline void PA4_set_inverted(const bool inverted)
{
	PORTA_pin_set_inverted(4, inverted);
}
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

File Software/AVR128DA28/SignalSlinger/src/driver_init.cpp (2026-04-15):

/*
 *  MIT License
 *
 *  Copyright (c) 2026 DigitalConfections
 *
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
 *  THE SOFTWARE IS PROVIDED "AS IS", WITHOUT WARRANTY OF ANY KIND, EXPRESS OR
 *  IMPLIED, INCLUDING BUT NOT LIMITED TO THE WARRANTIES OF MERCHANTABILITY,
 *  FITNESS FOR A PARTICULAR PURPOSE AND NONINFRINGEMENT. IN NO EVENT SHALL THE
 *  AUTHORS OR COPYRIGHT HOLDERS BE LIABLE FOR ANY CLAIM, DAMAGES OR OTHER
 *  LIABILITY, WHETHER IN AN ACTION OF CONTRACT, TORT OR OTHERWISE, ARISING FROM,
 *  OUT OF OR IN CONNECTION WITH THE SOFTWARE OR THE USE OR OTHER DEALINGS IN THE
 *  SOFTWARE.
 */


/*
 * High-level board bring-up and alternate hardware-configuration entry points.
 *
 * This module contains support functions for:
 * - full system initialization during normal firmware startup
 * - reduced pin/peripheral setup for charging-specific operation
 * - low-power hardware preparation before sleep
 *
 * Application behavior after initialization belongs elsewhere.
 */

#include "defs.h"
#include "driver_init.h"
#include <system.h>
#include "usart_basic.h"
#include "serialbus.h"
#include "binio.h"
#include "rtc.h"
#include "adc.h"


/**
 * Perform the normal firmware hardware bring-up sequence.
 */
void system_init()
{
	mcu_init();

	/* Bring up the foundational clock/timer/RTC path before enabling interrupts. */
	CLKCTRL_init(); /* Set CPU clock speed appropriately */
	TIMERB_init(); /* Timers must be initialized before utility_delay functions will work */
	RTC_init(); /* Start 1-second timer and interrupts */
	CPUINT_init(); /* Interrupts must also be enabled before timer interrupts will function */
	BINIO_init();

	SLPCTRL_init();
	ADC0_SYSTEM_init(SINGLE_CONVERSION);
	
//	serialbus_init(SB_BAUD, SERIALBUS_USART);

	BOD_init();
}

/**
 * Configure the subset of hardware needed for charging-related operation.
 */
void system_charging_config()
{
	ADC0_SYSTEM_init(SINGLE_CONVERSION);

//	mcu_init();

//	CLKCTRL_init(); /* Set CPU clock speed appropriately */
//	TIMERB_init(); /* Timers must be initialized before utility_delay functions will work */
//	RTC_init(); /* Start 1-second timer and interrupts */
//	CPUINT_init(); /* Interrupts must also be enabled before timer interrupts will function */

//	BINIO_init();
	/* Enable only the hardware required for power and battery monitoring in this mode. */
		/* PORTA *************************************************************************************/
  	PORTA_set_pin_dir(AUX_SWITCH_ENABLE, PORT_DIR_OUT);
  	PORTA_set_pin_level(AUX_SWITCH_ENABLE, HIGH); // Turn on the shared auxiliary switch
// 	
//  	PORTA_set_pin_dir(FET_DRIVER_ENABLE, PORT_DIR_OUT);
// 	PORTA_set_pin_level(FET_DRIVER_ENABLE, HIGH);
// 
	PORTA_set_pin_dir(POWER_ENABLE, PORT_DIR_OUT); /* Enables/latches battery power to +VSW */
	PORTA_set_pin_level(POWER_ENABLE, HIGH);
// 
//  	PORTA_set_pin_dir(PADDLE_DIT, PORT_DIR_IN);
// 	PORTA_set_pin_pull_mode(PADDLE_DIT, PORT_PULL_OFF);
// 
//  	PORTA_set_pin_dir(PADDLE_DAH, PORT_DIR_IN);
// 	PORTA_set_pin_pull_mode(PADDLE_DAH, PORT_PULL_OFF);
// 
// 	PORTA_set_pin_dir(STRAIGHTKEY, PORT_DIR_OUT);
// 	PORTA_set_pin_level(STRAIGHTKEY, LOW);
// 	
// 	PORTA_set_pin_dir(V3V3_PWR_ENABLE, PORT_DIR_OUT);
// 	PORTA_set_pin_level(V3V3_PWR_ENABLE, LOW);
// 	
// 	PORTA_set_pin_dir(BOOST_PWR_ENABLE, PORT_DIR_OUT);
// 	PORTA_set_pin_level(BOOST_PWR_ENABLE, LOW);
	
	/* PORTC *************************************************************************************/
	
// 	PORTC_set_pin_dir(SERIAL_TX, PORT_DIR_OUT);
// 	PORTC_set_pin_dir(SERIAL_RX, PORT_DIR_IN);
// 	PORTC_set_pin_dir(SI5351_SDA, PORT_DIR_OUT);
// 	PORTC_set_pin_dir(SI5351_SCL, PORT_DIR_IN);
	
	/* PORTD *************************************************************************************/
	PORTD_set_pin_dir(VBAT_INT, PORT_DIR_IN);
	PORTD_set_pin_pull_mode(VBAT_INT, PORT_PULL_OFF);
	PORTD_set_pin_dir(VBAT_EXT, PORT_DIR_IN);
	PORTD_set_pin_pull_mode(VBAT_EXT, PORT_PULL_OFF);
// 
// 	PORTD_set_pin_dir(LED_RED, PORT_DIR_OUT);
// 	PORTD_set_pin_level(LED_RED, LOW);
// 
// 	PORTD_set_pin_dir(SWITCH, PORT_DIR_IN);
// 	PORTD_set_pin_pull_mode(SWITCH, PORT_PULL_UP);
// 	PORTD_pin_set_isc(SWITCH, PORT_ISC_FALLING_gc);
// 	
// 	PORTD_set_pin_dir(LED_GREEN, PORT_DIR_OUT);
// 	PORTD_set_pin_level(LED_GREEN, LOW);
// 
// 	g_adc_initialization = ADC_NOT_INITIALIZED; /* Reset ADC configuration */

	/* PORTF *************************************************************************************/
// 	PORTF_set_pin_dir(X32KHZ_SQUAREWAVE, PORT_DIR_OFF);	


//	SLPCTRL_init();

//	serialbus_init(SB_BAUD, SERIALBUS_USART);

//	BOD_init();
}

/**
 * Restore the awake-mode peripheral configuration after standby wake.
 *
 * This resume path intentionally skips RTC reinitialization so the 1 Hz
 * timebase keeps its existing phase and does not slip on every serial wake.
 */
void system_resume_from_standby()
{
	mcu_init();

	/* Rebuild the normal awake-time peripheral configuration, but preserve the
	 * RTC state established before sleep.
	 */
	CLKCTRL_init();
	TIMERB_init();
	CPUINT_init();
	BINIO_init();

	SLPCTRL_init();
	ADC0_SYSTEM_init(SINGLE_CONVERSION);

	BOD_init();
}

/**
 * Reconfigure hardware into the low-power sleep arrangement expected by the firmware.
 */
void system_sleep_config()
{
	mcu_init();
	ADC0_SYSTEM_shutdown();

	/* Shut down timer-driven services that are not meant to run through deep sleep. */
//	CLKCTRL_init(); /* Set CPU clock speed appropriately */
	TIMERB_sleep(); /* Timers must be initialized before utility_delay functions will work */
//	CPUINT_init(); /* Interrupts must also be enabled before timer interrupts will function */
//	BINIO_init();

	LED_set_RED_dir(PORT_DIR_OUT);
	LED_set_RED_level(OFF);
	LED_set_GREEN_dir(PORT_DIR_OUT);
	LED_set_GREEN_level(OFF);

	/* Re-drive externally visible outputs into known low-power states before sleeping. */
// 	PORTA_set_pin_dir(AUX_SWITCH_ENABLE, PORT_DIR_OUT);
// 	PORTA_set_pin_level(AUX_SWITCH_ENABLE, LOW);
// 	PORTA_set_pin_dir(FET_DRIVER_ENABLE, PORT_DIR_OUT); /* Don't turn off charging in case internal battery is charging */
// 	PORTA_set_pin_level(FET_DRIVER_ENABLE, LOW);
	PORTA_set_pin_dir(V3V3_PWR_ENABLE, PORT_DIR_OUT);
	PORTA_set_pin_level(V3V3_PWR_ENABLE, LOW);
// 	PORTA_set_pin_dir(POWER_ENABLE, PORT_DIR_OUT); /* Must not disable battery power if running off of battery */
// 	PORTA_set_pin_level(POWER_ENABLE, LOW); /* Must not disable battery power if running off of battery */
 	PORTA_set_pin_dir(PADDLE_DIT, PORT_DIR_IN);
 	PORTA_set_pin_pull_mode(PADDLE_DIT, PORT_PULL_OFF);
	PORTA_set_pin_dir(PADDLE_DAH, PORT_DIR_OUT);
	PORTA_set_pin_level(PADDLE_DAH, LOW);
#ifdef HW_TARGET_3_5
	PORTA_set_pin_dir(COOLING_FAN_ENABLE, PORT_DIR_OUT);
	PORTA_set_pin_level(COOLING_FAN_ENABLE, LOW);
#else
	PORTA_set_pin_dir(BOOST_PWR_ENABLE, PORT_DIR_OUT);
	PORTA_set_pin_level(BOOST_PWR_ENABLE, LOW);
#endif
	PORTA_set_pin_dir(STRAIGHTKEY, PORT_DIR_OUT);
	PORTA_set_pin_level(STRAIGHTKEY, LOW);
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

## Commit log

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2023-07-23 Ver 0.90
    Corrects an error in serial port comms.
    Brings in fixes from NanoFox
    [defs.h, main.cpp, serialbus.cpp]
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2023-10-09 Debug
    o Adds I2C debug error logging
    o Adds device types: Fox, QRP, or siggen
    [i2c.cpp, main.cpp]
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2023-11-25 Updates
    PCB and FreeCAD file updates. PCB layout improved to ensure all parts fit without interference.
    [DB9-connector-mock-up.3mf, DB9-connector-mock-up.stl, PCB.FCStd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]
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2023-12-30 Ver 0.104
    Added support for green LED.
    Corrected some bugs that could affect battery drain.
    [atmel_start_pins.h, binio.cpp, defs.h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]
2024-01-17 Ver 0.105
    Small bug fix: When pressing the pushbutton while unit is sleeping, only the LEDs should be revived, and it should not trigger an event to start. That is now the case with these changes.
    Also improved support for red and green LED enunciations.
    [defs.h, main.cpp]
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2024-06-13 BOM Corrections
    o Updated Footprints
    o Updated PCB and Gerbers
    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
    [Misc.kicad_sch, PowerSupply.kicad_sch, RF_Filters.kicad_sch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]
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2024-08-29 Ver 0.22
    Fixes two bugs:
    1. When set to Beacon the frequency would not always get set correctly
    2. KEY 1 command would timeout randomly and the transmitter would not get reset properly. Now KEY 1 keydown times out after 10 seconds.
    [binio.cpp, binio.h, defs.h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]
2024-09-19 Ver 0.26
    o Software now disables boost voltage regulator until the user enables the transmitter by pressing the button eight times.
    o Fixes some LED bugs
    o LEDs will blink alternately red then green if the device is disabled.
    o Warning messages are printed to the serial port if the device is disabled.
    [defs.h, main.cpp]
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2024-11-28 Ver 0.34
    Added prints on power up and wake up
    Fixed util_delay_ms()
    [defs.h, main.cpp, tcb.cpp]
2024-12-28 Ver 0.36
    o Corrects a bug that could prevent the frequency from being set correctly when switching between Beacon and other transmitter roles.
    o Corrects a bug that could cause the output power not to be set correctly when testing the transmitter with it set to cloning mode.
    [defs.h, main.cpp]
2025-01-19 Ver 0.41
    Full feature support requires hardware modification to PCB Ver 3.4. This software version provides support for removing internal battery charging power from MOD101 when charging from external battery power and the internal battery is sufficiently charged. This requires the use of U204 to control the power reaching MOD101.
    Numerous bug fixes and enhancements to battery conservation are also included in this software version. Compatibility with HW Ver 3.4 hardware is still being evaluated.
    [adc.cpp, binio.cpp, binio.h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]
2025-01-19 Ver 0.42
    Corrects a bug that could result in the transmit frequency not being set correctly.
    [binio.cpp, defs.h, main.cpp]
2025-01-26 Ver 0.49
    o Provides a stored setting for enabling the boost regulator. It is set by the BAT B 1/0 command
    o Numerous bug fixes and coding improvements (still more to come)
    [binio.cpp, binio.h, defs.h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]
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2025-07-25 Ver 0.70
    o Fixes the bug that broke cloning in 0.50 and 0.60
    o More fully implements disabling power from an external battery, but the feature is not fully verified
    o Makes events timed to start in the future more robust, by always configuring them to run unless the current clock time is reset
    o Displays processor temperature (current, maximum, and minimum since power up) over the serial port
    o Prints an error message if the processor temperature exceeds 60C. Message is cleared when the temperature falls below 55C.
    [adc.cpp, defs.h, main.cpp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]
2025-08-02 Ver 0.72
    o After a successful cloning, while the “success” blink pattern is blinking, a keypress will now reset the success state and return a target device to normal operation without causing transmissions to start.
    o Charging from the external battery now works when the BAT X 1 or BAT X 2 command is in effect.
    o The BAT X 2 command shuts off radio transmissions and causes warning messages to appear on serial port communications.
    o The BAT T float command will now set the threshold value at which the green LED blinks to indicate a low internal battery; the same threshold value is used to determine when internal battery charging occurs using a switched external battery (if the externa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
    [binio.cpp, binio.h, defs.h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]
2025-08-04 Ver 0.73
    o Corrects a problem that could sometimes cause cloning to fail, especially when the target had recently had is EEPPROM re-initialized.
    [defs.h, main.cpp, serialbus.h]
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2025-10-29 SW Ver 1.0
    First production software version.
    o The device disabled LED blink pattern now indicates that self-check found no errors.
    [defs.h, main.cpp]
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2025-11-16 Meshtastic Support
    o Prevents sending the settings if a Meshtastic header is received just before a valid command.
    [main.cpp, serialbus.cpp]
2025-11-16 Meshtastic Support
    o Fix for GO 0 not shutting down a running event
    o Fix for 3 buttonpresses no shutting down a running event
    [main.cpp]
2025-11-18 Meshtastic Support
    o All commands now respond with a short reply indicating success or failure
    o Added TMP command for retrieving the processor temperature
    [main.cpp, serialbus.h]
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2025-11-30 Ver 1.1d
    o Fixes an issue with the serial port wake from interrupt not always waking SignalSlinger up.
    o Corrects several issues preventing external battery control from operating reliably.
    [binio.cpp, defs.h, driver_init.cpp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]
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2026-01-11 Ver 1.1h
    Corrects a problem when going to sleep: a single character would be sent when the UART port TX pin was initialized. This would be sent if a Meshtastic node were attached, waking up all the other nodes that receive the message.
    [defs.h, driver_init.cpp, main.cpp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]
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2026-01-19 Version 1.1i
    o Corrects an error that could cause timed transmissions not to occur when using serial commands to commence an event (GO 1 or GO 2)
    o Provides a 30-sec test signal with a single button press under most circumstances. This is intended to simplify antenna tuning.
    [defs.h, driver_init.cpp, main.cpp]
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2026-01-20 Ver 1.1k
    o GO 0 now resets event timing just the way KEY 0 does.
    [defs.h, main.cpp]
2026-01-28 Ver 1.1m
    o Major rework related to starting and stopping events
    o GO 0, GO 1, GO 2 should work reliably now in all event types
    o Single and triple pushbutton presses should work reliably and support antenna tune keydown
    o Refactored many variables to match the concept of an "Event Engine"
    o Fan now works in 3.5 hardware
    o Thermal shutdown should now work
    o CLK S is now forced to align with 5-min intervals
    [binio.cpp, binio.h, defs.h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]
2026-01-31 Ver 1.1n
    o Corrects a problem with CLK T and CLK S that could prevent the transmitter from coming on the air at the correct transmit time slot.
    o Corrects a problem with printing temperature that could result in, e.g., 25.10C being printed instead of 25.9C.
    [defs.h, main.cpp]
2026-02-01 Ver 1.1o
    Corrects an error that could prevent a keypress from being recognized immediately after a single keypress was read following power-up. This could prevent a user from cancelling a keydown.
    [defs.h, main.cpp]
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2026-02-04 Ver 1.1p
    o Various bug fixes for button-press event starting and stopping.
    o Fixes for sleep-related issues when events end, or the device is put to sleep with a long button press.
    [defs.h, main.cpp]
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2026-02-26 Add globals.h and update volatile globals
    Add include/globals.h to centralize extern declarations for cross-translation-unit globals (with header guard). Update several translation units to harmonize qualifiers: mark shared globals volatile where appropriate and change extern declarations accordingly (main.cpp, serialbus.cpp, leds.cpp, driver_isr.cpp). Make g_serialbus_usart_number volatile for ISR usage and convert various flags/counters (g_cloningInProgress, g_enunciator, g_isMaster, isMasterCountdownSeconds, etc.) to volatile to match definitions and avoid linkage/type mismatches and potential concurrency issues.
    [main.cpp, serialbus.cpp]
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2026-02-26 Make time handling atomic and thread-safe
    Add atomic_read_time and completeTimeString_volatile helpers and switch several time-related APIs/uses to volatile time_t to avoid races with ISR updates. validateTimeString now accepts volatile time_t*, and callers in handleSerialBusMsgs use atomic reads or completeTimeString_volatile. eventIsScheduledToRun(volatile...) was implemented to copy start/finish under critical sections, call the non-volatile checker, and restore values while holding locks. These changes introduce ENTER_CRITICAL/EXIT_CRITICAL regions (main_time_read, main_event_sched_read/write) to ensure consistent reads/writes of shared epoch variables.
    [main.cpp]
2026-02-26 Use atomic reads for shared globals
    Add atomic_read_float and atomic_read_u32 helpers (using ENTER_CRITICAL/EXIT_CRITICAL) and expand use of atomic_read_time. Replace many direct volatile/global reads with atomic reads and local cached copies (battery voltages, thresholds, timestamps, processor temps, event checksums and event epochs) to avoid race conditions when values are updated in interrupt/context-switching code. Also adjust logic to use the cached atomic values where appropriate and tidy indentation/formatting. This change improves thread-safety of status checks and reporting without changing behavior.
    [main.cpp]
2026-02-26 Add atomic time-pair reader and use it for epochs
    Introduce atomic_read_time_pair() to atomically snapshot two time_t values inside a critical section. Replace many direct reads/writes of paired epoch variables (g_event_start_epoch/g_event_finish_epoch and g_evteng_loaded_start_epoch/g_evteng_loaded_finish_epoch) across main.cpp with calls to the new helper to ensure consistent start/finish timestamps and avoid race conditions. Also use atomic_read_time for single-time reads during cloning. Changes update initialization, sleep/event logic, setup/start/suspend flows, serial handlers, and other places where paired epoch consistency is required.
    [main.cpp]
2026-02-26 Use atomic reads for time variables
    Replace direct accesses to shared time globals with atomic_read_time and atomic_read_time_pair and operate on local time_t copies. This prevents race conditions between ISRs and main code when checking wake-up, event start/finish times, and when rolling event epochs to the next day. Adjusted sleep/wake logic and TCB handling to use the local copies while preserving existing behavior (e.g. wake-up-before-showtime and multi-day event handling).
    [main.cpp]
2026-02-26 Fix brace/scoping issues in event handlers
    Adjust main.cpp (ISR(RTC_CNT_vect) and handle_1sec_tasks) to add explicit braces and correct scoping/indentation for several if/else blocks. This ensures wake/sleep flags, event start/finish detection, and sleep-type transitions are executed only when intended (including moving temp_time assignment and clarifying event scheduling checks). These changes prevent unintended fall-through behavior that could cause incorrect sleep handling or event timing.
    [main.cpp]
2026-02-26 Add atomic time write helpers and use them
    Introduce atomic_write_time and atomic_write_time_pair (using ENTER_CRITICAL/EXIT_CRITICAL) and replace numerous direct assignments to shared time variables with these helpers. This ensures paired and single time_t updates (e.g. g_evteng_loaded_* , g_event_* , g_time_to_wake_up) are performed atomically to avoid race conditions and inconsistent state during concurrent reads/writes.
    [main.cpp]
2026-02-26 Protect text buffer with atomic access
    Introduce atomic wrappers and critical sections for g_text_buff to prevent race conditions between ISR and main code. Added text_buff_empty_atomic, text_buff_reset_atomic, and text_buff_try_get_atomic in main.cpp and a text_buff_reset_and_disable_manual_atomic helper in leds.cpp; replaced direct g_text_buff.empty()/reset()/get() usages with these atomic helpers. Also added <atomic.h> include and adjusted leds::sendCode to perform buffer mutation inside a critical section while preserving g_enable_manual_transmissions state. These changes ensure thread-safe access to the circular text buffer from interrupts and foreground code.
    [main.cpp]
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2026-02-26 Make message text access atomic
    Add atomic accessors for g_messages_text and use critical sections to prevent races between ISRs and foreground code. main.cpp: declare and implement messages_text_slot_clear_atomic and messages_text_slot_write_atomic and replace direct g_messages_text[] writes with these helpers. eeprommanager.cpp: include atomic.h, add messages_text_slot_clear_atomic and messages_text_slot_publish_atomic, read EEPROM into local buffers then publish to g_messages_text via the atomic publisher, and use the clear/publish helpers when initializing defaults. Ensures NUL termination and safer strncpy bounds to avoid partial/corrupt message state during concurrent access.
    [main.cpp]
2026-02-26 Atomic-copy patterns before calling makeMorse
    Add thread-safe helpers to snapshot message text before invoking makeMorse. Introduces messages_text_slot_copy_atomic to copy a message slot inside a critical section, plus loadCurrentPatternMorse and loadStationIDMorse which take local snapshots (or atomic copies) of the pattern or station ID and call makeMorse with the snapshot. Replace direct makeMorse(getCurrentPatternText()/g_messages_text[STATION_ID], ...) calls throughout main.cpp to prevent races on g_messages_text and ensure stable null-terminated buffers when generating Morse.
    [main.cpp]
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2026-02-26 Fix control-flow/brace bugs and cleanup
    Correct misplaced braces and scope in ISR and main event handling to ensure statements execute as intended, and consolidate/clean up related logic. Changes include: fix charFinished/bracing in TCB0 ISR, tighten event scheduling/start/stop handling (add proper braces and remove duplicated branches), remove duplicate hardware-error checks and simplify LED/status decision tree, and tidy up serial-bus message handling and small formatting/indentation issues. These changes prevent unintended fall-through behavior and reduce redundant code while keeping existing behavior intact.
    [main.cpp]
2026-02-26 Use atomic accessors for fox settings
    Add atomic read/write helpers for fox settings and event+fox snapshots (critical-section protected) in shared_state.h: fox_setting_current_atomic, event_and_fox_current_atomic, fox_setting_slot_write_atomic, and fox_setting_current_slot_write_atomic. Replace direct g_fox[] accesses in main.cpp with the new getFoxSetting() (which now calls fox_setting_current_atomic) and atomic write helper (fox_setting_current_slot_write_atomic) at call sites to ensure thread-safe reads/writes. Update EEPROM initialization in eeprommanager.cpp to write fox defaults/read values via fox_setting_slot_write_atomic instead of assigning g_fox[] directly. These changes improve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
    [main.cpp]
2026-02-26 Add ISR-safe echo FIFO and atomic I2C timeouts
    Introduce an ISR-safe serial echo FIFO and non-blocking echo path, and make I2C timeout/tick accesses atomic to avoid races. Changes include: driver_isr.cpp — restructure CR handling to publish completed message atomically and use sb_echo_char_isr for non-blocking ISR echo; DRE ISR now services ISR echo FIFO before TX buffers. serialbus.h/serialbus.cpp — add ISR echo FIFO, sb_echo_char_isr and serialbus_echo_try_get_isr, reset logic, and make serial send publish atomic to prevent partially-populated buffers being transmitted. shared_state.h — add atomic_read_u16/atomic_write_u16 helpers. i2c.cpp — use atomic read/write for g_i2c0_timeout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
    [i2c.cpp, serialbus.cpp, serialbus.h]
2026-02-26 Add spin guards to I2C and serialbus waits
    Introduce local spin_guard counters to I2C wait loops and serialbus transmit waits to prevent potential infinite spins if the atomic timeout ticks are not decremented. Adjust I2C error detection to use the internal state variable (setting I2C_ERROR on timeout) and ensure failure_count increments on error. Update serialbus logic to consider both the spin_guard and the atomic timeout when deciding a transmit error. These changes add a defensive timeout layer to improve robustness against stalled hardware or missed tick updates.
    [i2c.cpp, serialbus.cpp]
2026-02-26 Make shared counters atomic; defer serial init
    Add atomic_exchange_u16 to shared_state.h and convert shared counters to atomic access to prevent races between ISRs and the main loop. Replace direct reads/writes to g_button_hold_countdown and g_foreground_handle_counted_presses with atomic_read/atomic_write/atomic_exchange. Introduce g_foreground_enable_serialbus flag and move serialbus_init out of the ISR into the main loop to avoid performing heavy initialization in an interrupt context. Re-prime debounce history in switchIsClosed to avoid stale samples and remove an unused startup variable. Overall changes improve thread-safety and ISR behavior.
    [main.cpp]
2026-02-26 Use atomic u16 accessors for shared state
    Add atomic_max_u16 to shared_state.h and replace direct accesses to shared uint16_t globals with atomic_read_u16/atomic_write_u16/atomic_exchange_u16/atomic_max_u16 in main.cpp. This converts many sleep/countdown/programming/cloning/reporting and master-related variables to use atomic operations (e.g. g_evteng_sleepshutdown_seconds, g_demo_event_countdown, g_key_down_countdown, g_send_clone_success_countdown, g_programming_countdown, g_programming_msg_throttle, g_report_settings_countdown, isMasterCountdownSeconds, etc.) to avoid race conditions between foreground code and ISRs. Also updates the sentinel assignment for programming countdown to use at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
    [main.cpp]
2026-02-26 Make start-event-after-keydown global and handle sync
    Introduce g_start_event_after_keydown (foreground-only) and replace the previous local start_event_after_keydown usage throughout main.cpp. In the serial bus handler, add logic to consider a pending start-after-keydown, cancel manual transient states (keydown/demo countdowns and foreground reset flags) so CLK T can re-sync immediately, and treat the pending flag as a reason to start a synced event now. These changes ensure one-press keydown can reliably launch a synced event and avoid stale countdowns delaying behavior.
    [main.cpp]
2026-02-26 Cancel transient on event active, call suspendEvent
    In handleSerialBusMsgs(), extend the conditions that cancel a manual transient state to include g_evteng_event_commenced and g_evteng_event_enabled so active/enabled events prevent unintended transient behavior. Also call suspendEvent() when clearing the transient flags to ensure any ongoing event activity is properly suspended.
    [main.cpp]
2026-02-26 Add cancelManualTransientState and fix mesh publish
    Introduce cancelManualTransientState() to centralize clearing of transient/manual-start state (keydown/demo countdowns, start-after-keydown flags, foreground resets, test frequency) and call it from serial bus message handlers before actions that stop/start events or update EEPROM. In driver_isr.cpp adjust Meshtastic mesh-mode handling to populate message fields before setting buff->id (publish last) and simplify invalid-prefix handling so the foreground sees a fully-populated buffer. These changes prevent stale keydown/demo states from affecting immediate commands (CLK, key events, event start/stop, EEPROM updates) and ensure mesh-mode mes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
    [main.cpp]
2026-02-26 Clear manual transient state during cloning
    Call cancelManualTransientState() in handleSerialBusMsgs to avoid manual transient states interfering with cloning and event setup. Changes: when fox setting changes (unless cloning), before starting a clone (on 'P' request), and after successful clone acknowledgment (MAS ACK) the manual transient state is cleared. This ensures suspendEvent/setupForFox and programming countdown logic run with a clean transient state and prevents unexpected behavior during cloning.
    [main.cpp]
2026-02-26 Refactor handleSerialBusMsgs control flow
    Reorganize and clean up the control flow, bracing, and indentation inside handleSerialBusMsgs. Case blocks for SB_MESSAGE_KEY, SB_MESSAGE_GO, SB_MESSAGE_MASTER, SB_MESSAGE_EVENT and related branches were restructured: condition checks and atomic writes were moved for clearer nesting, device-disabled responses were consolidated, cloning/master handling was clarified, and several duplicated/misnested sections were fixed. These edits are primarily readability and flow-structure improvements to make the message handling logic easier to follow and maintain.
    [main.cpp]
2026-03-24 Add startEvent() and refactor event start logic
    Add a .clang-format config and bump SW_REVISION to 1.2b while enabling HW_TARGET_3_4 in defs.h. Extract duplicated event-start sequence into a new startEvent() helper and replace repeated inline blocks with calls to it. Adjust serial/clone handling to respect cloning state and to ACK/NACK clone commands based on startEvent() result. Also tidy up battery/charging conditional formatting and other minor whitespace/format fixes.
    [defs.h, main.cpp]
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2026-03-24 Add atomic_set_system_time wrapper
    Introduce atomic_set_system_time(time_t, bool) to perform set_system_time inside a critical section and optionally reset the RTC. Replace direct calls to RTC_zero()/set_system_time() with this atomic wrapper in main and handleSerialBusMsgs to prevent races during time updates and centralize the RTC-reset behavior.
    [main.cpp]
2026-03-24 Fix indentation and comment spacing in main.cpp
    Adjust whitespace and alignment in main.cpp for readability. Normalize spacing on the on_air/off_air variable comments and fix indentation of the atomic_set_system_time call inside handleSerialBusMsgs; no functional changes intended.
    [main.cpp]
2026-03-24 Use g_sleepType comparison for sleep check
    Fix conditional in main.cpp to compare the runtime variable g_sleepType to SLEEP_UNTIL_NEXT_XMSN instead of testing the constant directly. This prevents the branch from always evaluating true and ensures transmit circuits are only powered up when the current sleep type indicates the next transmission.
    [main.cpp]
2026-03-24 Add reinitializeEventEngine helper and use it
    Factor out the repeated event-engine initialization sequence into a new static function reinitializeEventEngine(). Added the function prototype and implementation, and replaced multiple inline occurrences of setting g_evteng_initialize_event, calling util_delay_ms(0), and waiting in a loop with calls to the new helper in main.cpp. This reduces duplication and centralizes the event engine initialization/wait logic without changing behavior.
    [main.cpp]
2026-03-24 Minor tweaks
    Corrects an error in EEPROM related to a debug value that was stored with the wrong size. Corrects some help text. Removes a comment.
    [main.cpp, serialbus.h]
2026-03-24 Ack clone before restarting event
    When a clone completes, send the ACK and set the clone-success countdown before attempting to restart the event so the target stays in clone-safe parsing mode. Replace the previous startEvent() path with logic that determines whether the cloned event should be restarted via eventIsScheduledToRun and sets g_foreground_start_event accordingly. Also defer clearing g_cloningInProgress and g_programming_countdown until after the ACK/NAK handling to avoid leaving clone mode too early.
    [main.cpp]
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
